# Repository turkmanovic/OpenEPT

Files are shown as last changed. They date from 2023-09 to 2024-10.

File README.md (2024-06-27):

# Energy Profiler Toolset
Easy-to-use, low-cost, open-source solution that includes compatible hardware and software sets of tools. This comprehensive solution is designed to fulfill the need for firmware energy profiling, as well as State of Charge (SoC) and State of Health (SoH) algorithm evaluation for real LiPo battery-powered embedded devices.

Official product website 
[OpenEPT](https://openept.net/)

Official [youtube](https://www.youtube.com/playlist?list=PLTG-EoxvlLos_3Sex3R0yfDCwpDYyRSOo) channel 

# Supported by
NLNet (https://nlnet.nl/)

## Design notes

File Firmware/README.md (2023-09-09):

# Firmware for energy profiler development board
Source code for STM based MCU located on EP development board

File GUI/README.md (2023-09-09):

# GUI for energy profiler development board
Source code for Qt based GUI application for energy monitoring end debugging



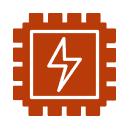
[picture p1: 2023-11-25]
GUI/OpenEPT/images/main.png

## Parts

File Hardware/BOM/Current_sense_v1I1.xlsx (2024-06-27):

Line # | Name | Description | Designator | Quantity | TargetPrice | Manufacturer 1 | Manufacturer Part Number 1 | Manufacturer Lifecycle 1 | Supplier 1 | Supplier Part Number 1 | Supplier Unit Price 1 | Supplier Subtotal 1 | ComponentLink1URL
 | 1uF | Multilayer Ceramic Capacitor, 1 uF, 50 V, ± 10%, X7R, 1206 [3216 Metric] | C1, C8, C9 | 3 | 0 | KEMET | C1206C105K5RACTU | Volume Production | Mouser | 80-C1206C105K5R | 0.26 | 0.78 | https://datasheet.ciiva.com/6074/kem-c1002-x7r-smd-6074697.pdf?src-supplier=Farnell
 | 3.3nF | Cap Ceramic 0.0033uF 100V C0G 1% SMD 1206 125°C Embossed T/R | C2 | 1 | 0 | Kyocera AVX | 12061A332FAT2A | Volume Production | Mouser | 581-12061A332FAT2A | 0.86 | 0.86 | https://datasheet.ciiva.com/11536/ccog-11536655.pdf?src-supplier=Avnet
 | 100uF/25V | Cap, 100Uf, 25V, Alu Elec, Hybrid, Smd Rohs Compliant: Yes |Wurth Elektronik 875585344001 | C3 | 1 | 0 | Wurth Electronics | 875585344001 | Unknown | Mouser | 710-875585344001 | 1.39 | 1.39
 | 0.47uF | Cap Ceramic 0.47uF 25V X7R 5% SMD 1206 125°C Embossed T/R | C4 | 1 | 0 | Kyocera AVX | 12063C474JAT2A | Volume Production | Mouser | 581-12063C474J | 0.43 | 0.43 | https://datasheet.ciiva.com/211/cx7r-211340.pdf?src-supplier=Digi-Key
 | 100n | 1206 Standard 100nF Ceramic Multilayer Cap; 50VDC; +150C; X8R Dielectric; +/-10% SMD | C5, C6, C7, C20, C21, C22, C23, C24, C25 | 9 | 0 | Kyocera AVX | 12065F104K4T2A | Volume Production | Mouser | 581-12065F104K4 | 0.172 | 1.72 | https://datasheet.ciiva.com/11787/0900766b80def347-11787814.pdf?src-supplier=Rs
 | 22uF/16V | Aluminum Electrolytic Capacitors - SMD 22uF 16V | C10, C11, C13, C14 | 4 | 0 | United Chemi-Con | MVJ16VC22RME60TP | Volume Production | Mouser, [NoParam] | 661-MVJ16VC22RM, [NoParam] |  |  | http://www.mouser.com/search/ProductDetail.aspx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
 | 10uF/16V | Aluminum Electrolytic Capacitor, 10 uF, 16 V, ± 20%, 1000 hours @ 105°C, Radial Can - SMD | C12, C15 | 2 | 0 | Panasonic | EEE-HA1C100R | Volume Production | Mouser | 667-EEE-HA1C100R | 0.23 | 0.46 | https://datasheet.ciiva.com/11777/0900766b8102e3f9-11777432.pdf?src-supplier=Rs
 | 2.2n | 1206 2.2 nF 50V ±10 % Tolerance X7R Surface Mount Multilayer Ceramic Capacitor | C16, C17, C18, C19 | 4 | 0.29 | Kyocera AVX | 12065C222KAZ2A | Volume Production | Mouser | 581-12065C222KAZ2A | 0.29 | 1.16 | https://datasheet.ciiva.com/208/flexiterm-208276.pdf?src-supplier=Digi-Key
 | SS14 | SS14 Series 500 mV 1 A 40 V Max Reverse Voltage Schottky Rectifier - DO-214AC | D1, D3, D6, D7, D10, D11 | 6 | 0 | Vishay Semiconductors | SS14-E3/61T | Volume Production | Farnell | 9551280 | 0.311 | 1.87 | https://datasheet.ciiva.com/910/ss12-910696.pdf?src-supplier=Digi-Key
 | Red | LED Red 20 mcd (Typ.) @ 25 C (Axial) 2.1 V (Typ.) @ 25 C (Forward) PCB | D2, D4, D8 | 3 | 0 | Vishay | TLMS1100-GS08 | Volume Production | Farnell | 1440338 | 0.323 | 0.969 | https://datasheet.ciiva.com/4689/sml-lxl1206gc-tr-115211-4689614.pdf?src-supplier=Mouser
 | Green | Led, Quasarbrite, Green, T-3/4 (1.8Mm), 574 Nm, 2.2 V, 20 Ma, 170 Mcd Rohs Compliant: Yes | D5 | 1 | 0 | Vishay Lite-On | LTST-C190GKT | Volume Production | Mouser | 859-LTST-C190GKT | 0.23 | 0.23 | https://datasheet.ciiva.com/30105/sml-lxl1209sugc-tr-30105147.pdf?src-supplier=Onlinecomponents.com
 | 3V3 Zener | MMELF, 500mW, 2%, Small Signal Zener Diode | D9 | 1 | 0 | ON Semiconductor | MM5Z3V3T1G | Volume Production | Mouser | 863-MM5Z3V3T1G | 0.18 | 0.18
 | 2_PIN_254 | Conn Unshrouded Header PL 2 POS 2.54mm Solder ST Thru-Hole | J1, J5, J7, J10, J22 | 5 | 0 | Omron | XG8T-0241 | Volume Production | Mouser | 653-XG8T0241 | 0.16 | 0.8 | https://datasheet.ciiva.com/48561/en-xg8t-48561514.pdf?src-supplier=Avnet
 | Red Connector | Connector, Pcb, 2CONTACTS | J2, J4, J6 | 3 | 0 | Deltron | 571-0500-01 | Volume Production | Farnell | 1101127 | 1.39 | 4.17 | http://www.farnell.com/datasheets/2007771.pdf?src-supplier=Farnell
 | Black Connector | Connector, Pcb, 2CONTACTS | J3 | 1 | 0 | Deltron | 571-0100 | Volume Production | Farnell | 1494595 | 1.17 | 1.17 | https://datasheet.ciiva.com/12074/deltron-571-0100-4mm-90deg-single-socket-data-372703-12074316.pdf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
 | Battery connector clamp | Conn PC Board Terminal Block Receptacle 2 POS 2.54mm RA Through Hole 10A | J8 | 1 | 0 | TE Connectivity | 282834-2 | Volume Production | Farnell | 2112482 | 1.19 | 1.19 | https://datasheet.ciiva.com/16386/282834-2-16386363.pdf?src-supplier=Future+Electronics
 | PH2.0 battery connector | Connector, Header, 2Pos, 1Rows, 2Mm Rohs Compliant: Yes | J9 | 1 | 0 | TE Connectivity | 292133-2 | Volume Production | Mouser | 571-292133-2 | 0.4 | 0.4 | https://datasheet.ciiva.com/734/eng-cd-292133-p-734147.pdf?src-supplier=Digikey
 | Push Button | Switch Tactile N.O. SPST Round Button Gull Wing 0.05A 12VDC 1.57N SMD Tube | J11 | 1 | 0 | Diptronics | DTSM-61N-V-B | Volume Production | Mouser | 113-DTSM-61N-V-B |  |  | https://datasheet.ciiva.com/26337/707546-da-01-en-smd-taster-26337236.pdf?src-supplier=Conrad
 | 6 pin 2.54 mm male | 2.54mm (0.1") Pitch SIL Vertical PC Tail Pin Header, 7mm mating pin height, tin, 6 contacts | J12 | 1 | 0 | Harwin | M20-9730646 | Volume Production | Digikey | 952-1985-ND | 0.33 | 0.33 | https://datasheet.ciiva.com/6830/m20-973-6830695.pdf?src-supplier=Digi-Key
 | 10 pin male 2.54mm pitch | Conn Unshrouded Header HDR 50 POS 2.54mm Solder ST Thru-Hole Box | J13 | 1 | 0 | TE Connectivity | 5-825433-0 | Volume Production | Farnell | 3417736 | 3.94 | 3.94 | https://datasheet.ciiva.com/11751/0900766b800304ef-11751249.pdf?src-supplier=Rs
 | 20 pin 2.54 male straight | Conn, Header, 20POS, 2ROW, 2.54MM Rohs Compliant: Yes | J14 | 1 | 0 | Harwin | M20-9721045 | Volume Production | Mouser | 855-M20-9721045 | 0.98 | 0.98 | http://www.mouser.com/ds/2/181/Harwin_Product_Catalog_page_207-1131241.pdf?src-supplier=Mouser
 | 8 pin 2.54 male header | 2.54MM Pitch, Srsw, T/h, H | J15 | 1 | 0 | Molex | 0878910808 | Unknown | Mouser | 538-87891-0808 | 2.55 | 2.55
 | 28 pin male right angle | Headers & Wire Housings 28P 2R BRKAWAY HDR 2.54MM RA L-PRO SN | J16 | 1 | 0 | Molex | 0717640028 | Obsolete | Mouser | 538-71764-0028 | 5.14 | 5.14 | https://datasheet.ciiva.com/6862/717640004-sd-6862000.pdf?src-supplier=Digikey
 | power 8 pin | 2.54MM Pitch, Srsw, T/h, H | J17 | 1 | 0 | Molex | 0878910808 | Unknown | Mouser | 538-87891-0808 | 2.55 | 2.55
 | 4907 | USB C SMT / THM Jack Connector - Power Only - Pack of 10 | J18 | 1 | 0 | Keystone Electronics | 4907 | Volume Production | Mouser | 534-4907 | 0.2 | 0.2 | https://datasheet.ciiva.com/16507/m60-2p52-16507735.pdf?src-supplier=Future+Electronics
 | PCB-MB-01 | Installation BLock Colour: Transparent Material: Nylon 6/6 RMS-01 | J19, J20, J24, J25 | 4 | 0 | Essentra | PCB-MB-01 | Volume Production | Mouser | 144-PCB-MB-01 | 0.36 | 1.44 | https://datasheet.ciiva.com/11835/0900766b8002e29e-11835600.pdf?src-supplier=Rs
 | 39-10-1020 | Connector Wire to Board Header 2 Position 4.2mm Solder Right Angle Thru-Hole Bag | J21 | 1 | 0 | Molex | 039301020 | Volume Production | Mouser | 538-39-30-1020 | 0.56 | 0.56 | https://www.molex.com/pdm_docs/sd/039301020_sd.pdf?src-supplier=Digikey
 | Heat Sink | Heat Sink Passive TO-220 Radial Thru-Hole Aluminum 5.5°C/W Black Anodized | J23 | 1 | 0 | Aavid Thermalloy | 529702B02500G | Volume Production | Mouser | 532-529702B25G | 1.99 | 1.99 | https://datasheet.ciiva.com/15182/getdatasheetpartid-42755-15182474.pdf?src-supplier=Verical
 | 1uH | Drum Core Shielded Power Inductor Wirewound Ferrite 1uH 20% 1MHz 9.5A SMD T/R | L1, L2 | 2 | 0 | Pulse | PA4333.102NLT | Volume Production | Digikey | 553-3294-1-ND | 0.85 | 1.7 | http://productfinder.pulseeng.com/products/datasheets/P762.pdf?src-supplier=Digikey
 | TSM500P02CX RFG | Transistor Mosfet P-ch 20V 4.7A 3-PIN SOT-23 T/r | M1, M7, M13 | 3 | 0 | Taiwan Semiconductor | TSM500P02CX RFG | Volume Production | Digikey | TSM500P02CXRFGCT-ND | 0.5 | 1.5 | http://www.taiwansemi.com/products/datasheet/TSM500P02CX_A14.pdf?src-supplier=Digi-Key
 | 2N7002L | Mosfet, N-ch, Vdss 60VDC, Rds(on) 7.5 Ohms, ID+/-115MA, SOT-23 (TO-236), Pd 225MW, -55C | M2, M3, M4, M6, M8, M9, M12, M14, M15, M16, M18, M19, M20, M21, M22, M23, M24 | 17 | 0 | ON Semiconductor | 2N7002LT3G | Volume Production | Farnell | 1764537 | 0.125 | 2.13 | http://www.farnell.com/datasheets/2354034.pdf?src-supplier=Farnell
 | IRF4905STRLPBF | Transistor: P-MOSFET; unipolar; -55V; -74A; 0.02ohm; 3.8W; -55+175 deg.C; SMD; TO263 (D2PAK) | M5, M10, M11 | 3 | 0 | Infineon | IRF4905STRLPBF | Not Recommended for New Design | Farnell | 1298511 | 2.49 | 7.47
 | TK4R3E06PL,S1X | X35 Pb-F Power Mosfet Transistor To-220 Pd=87W F=1Mhz | M17 | 1 | 0 | Toshiba | TK4R3E06PL,S1X | Unknown | Mouser | 757-TK4R3E06PLS1X | 1.44 | 1.44
 | TSM250N02CX RFG | Transistor Power MOSFET N-CH 20V 5.8A 3-Pin SOT-23 T/R | M25, M26 | 2 | 0 | Taiwan Semiconductor | TSM250N02CX RFG | Volume Production | Mouser | 821-TSM250N02CXRFG | 0.43 | 0.86 | http://www.taiwansemi.com/products/datasheet/TSM250N02CX_A14.pdf?src-supplier=Digikey
 | 220 | Res, Aec-Q200, 220R, 1%, 0.5W, 1206 Rohs Compliant: Yes |Vishay RCC1206220RFKEA | R1, R19, R22, R24, R25, R31, R40 | 7 | 0 | Vishay Dale | RCC1206220RFKEA | Unknown | Mouser | 71-RCC1206220RFKEA | 0.128 | 1.28 | https://datasheet.octopart.com/RCC1206220RFKEA-Vishay-datasheet-151891907.pdf?src-supplier=Element14
 | 10k | SMD Chip Resistor, 10 kOhm, ± 5%, 250 mW, 1206 [3216 Metric], Thick Film, General Purpose | R2, R11, R14, R26, R39, R44, R45, R50, R51, R53, R54, R55, R57, R58, R60, R62, R63, R68, R69, R70 | 20 | 0 | Bourns | CR1206-JW-103ELF | Volume Production | Farnell | 2333546 | 0.0164 | 0.328 | https://datasheet.ciiva.com/6547/chpreztr-6547381.pdf?src-supplier=Digi-Key
 | 56k | Res Thick Film 1206 56K Ohm 1% 1/4W ±100ppm/°C Molded SMD SMD Paper Tape on Plastic Reel | R3 | 1 | 0 | Bourns | CR1206-FX-5602ELF | Volume Production | Mouser | 652-CR1206FX-5602ELF | 0.1 | 0.1 | https://datasheet.ciiva.com/9121/chpreztr-9121174.pdf?src-supplier=Avnet
 | 100k | Res Thick Film 1206 100kOhm 1/4W Molded Paper T/R | R4, R6, R7, R9, R18, R23, R27, R30, R32, R35, R36, R38, R46, R47, R49 | 15 | 0 | Vishay Dale | RCG1206100KJNEA | Volume Production | Mouser | 71-RCG1206100KJNEA | 0.139 | 2.09 | http://www.mouser.com/ds/2/427/rcge3-254226.pdf?src-supplier=Mouser
 | 680k | RES SMD 680K OHM 5% 1/4W 1206 | R5 | 1 | 0 | Bourns | CR1206-JW-684ELF | Volume Production | Digikey | 118-CR1206-JW-684ELFCT-ND | 0.1 | 0.1 | https://datasheet.ciiva.com/5544/chpreztr-5544750.pdf?src-supplier=Mouser
 | 560 | Res Thkflm D25/1206 560R Ohm 1% 100 ET6 E3 SMD | R8, R10, R34 | 3 | 0 | Vishay Dale | CRCW1206560RFKEC | Not Recommended for New Design | Mouser | 71-CRCW1206560RFKEC | 0.1 | 0.3 | http://www.vishay.com/docs/20035/dcrcwe3.pdf?src-supplier=Digi-Key
 | 220k | Resistor Thick Film 220kOhm 5% 2-Pin 1206 T/R | R12, R13 | 2 | 0 | Bourns | CHP1206AJW-224ELF | Unknown | Farnell | 3464682 | 0.538 | 1.08
 | 33k | SMD Chip Resistor, 33 kOhm, ± 5%, 250 mW, 1206 [3216 Metric], Thick Film, General Purpose | R15, R17, R41 | 3 | 0 | Yageo | RC1206JR-0733KL | Volume Production | Farnell | 9240705 | 0.0207 | 0.207 | https://datasheet.ciiva.com/29181/402729-da-01-en-smd-widerstand-chip1206-33-kohm-29181369.pdf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
 | 1M | SMD Chip Resistor, 1 MOhm, ± 5%, 250 mW, 1206 [3216 Metric], Thick Film, General Purpose | R16 | 1 | 0 | Bourns | CR1206-JW-105ELF | Volume Production | Farnell | 2469514 | 0.009 | 0.09 | https://datasheet.ciiva.com/9123/chpreztr-9123660.pdf?src-supplier=Avnet
 | 1k | Res Thick Film 1206 1kOhm 5% 1/4W ±200ppm/K Molded Paper Tape | R20, R21, R37, R43, R48 | 5 | 0 | Vishay Dale | RCA12061K00JNEA | Volume Production | Mouser | 71-RCA12061K00JNEA | 0.059 | 0.59 | http://www.vishay.com/docs/20037/rcae3.pdf?src-supplier=Digi-Key
 | 45mOhm | CURRENT SENSE, RESISTOR, WSLP1206.0451%EAe3 | Vishay Dale WSLP1206R0450FEA | R28 | 1 | 0 | Vishay | WSLP1206R0450FEA | Unknown | Digikey | WSLP1206R0450FEA-ND
 | 6.8k | Res Thick Film 1206 6.8K Ohm 1% 1/4W ±100ppm/°C Molded SMD SMD Paper Tape on Plastic Reel | R29 | 1 | 0 | Bourns | CR1206-FX-6801ELF | Volume Production | Mouser | 652-CR1206FX-6801ELF | 0.1 | 0.1 | https://datasheet.ciiva.com/9122/chpreztr-9122586.pdf?src-supplier=Avnet
 | 100 | SMD Chip Resistor, 100 Ohm, ± 5%, 250 mW, 1206 [3216 Metric], Thick Film, General Purpose | R33, R42, R64, R65, R66, R67 | 6 | 0 | Bourns | CR1206-JW-101ELF | Volume Production | Mouser | 652-CR1206JW-101ELF | 0.015 | 0.15 | https://datasheet.ciiva.com/9120/chpreztr-9120757.pdf?src-supplier=Avnet
 | 75mOhm | Res Current Sense Metal Strip 2512 0.075 Ohm 1% 3W ±25ppm/°C Molded Emboss T/R | R52 | 1 | 0 | CGS | TLRP3A30CR075FTE | Volume Production | Farnell | 3782978 | 0.476 | 0.476
 | 10 | Resistor, ResHighPowerA 1206 10R 1% 3/4W TC100 | R56, R59 | 2 | 0 | Bourns | CMP1206AFX-10R0ELF | Unknown | Mouser | 652-CMP1206AFX-10R0L | 0.39 | 0.78
 | 3.3k | Res Thick Film 1206 3.3K Ohm 1% 1/4W ±100ppm/°C Molded SMD SMD Paper Tape on Plastic Reel | R61 | 1 | 0 | Bourns | CR1206-FX-3301ELF | Volume Production | Digikey | CR1206-FX-3301ELFCT-ND | 0.1 | 0.1 | https://datasheet.ciiva.com/41449/001055537-da-01-en-smd-wid-cr1206-fx-3301elf-3-3k-ohm-1-4w-41449983.pdf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
 | 3V3 Regulator | IC REG LDO 3.3V 1A SOT223 | U1 | 1 | 0 | TI National Semiconductor | LM3940IMP-3.3/NOPB | Volume Production | Mouser | 926-LM3940IMP3.3NOPB | 1.9 | 1.9
 | TPS60400 | 60mA Charge Pump Voltage Inverter with Variable Switching Frequency 5-SOT-23 -40 to 85 | U2 | 1 | 0 | Texas Instruments | TPS60400DBVT | Volume Production | Farnell | 3123047 | 1.21 | 1.21 | https://datasheet.ciiva.com/15114/getdatasheetpartid-256453-15114097.pdf?src-supplier=Verical
 | TPS61023DRLR | 3.7-A boost converter with 0.5-V ultra-low input voltage 6-SOT-5X3 -40 to 125 | U3, U4 | 2 | 0 | Texas Instruments | TPS61023DRLR | Volume Production | Mouser | 595-TPS61023DRLR | 0.98 | 1.96 | http://www.ti.com/general/docs/suppproductinfo.tsp?distId=10&src-supplier=Digikey
 | RGB diode | WL-SFTW SMT full-color TOP LED waterclear | U5 | 1 | 0 | Wurth Electronics | 150352M173300 | Unknown | Farnell | 2900778 | 0.635 | 0.635 | http://www.farnell.com/datasheets/2621660.pdf?src-supplier=Farnell
 | INA296A1SOIC8 | Operational Amplifier, 1 Func, 150uV Offset-Max, PDSO5 | U6 | 1 | 0 | Texas Instruments | INA296A1IDDFR | Volume Production | Digikey | 296-INA296A1IDDFRCT-ND | 3.61 | 3.61
 | LM358DR | Operational Amplifier, Dual, 700 Khz, 2, 0.3 V/ S, 3V To 32V, 1.5V To 16V, Soic, 8 Rohs Compliant: Yes | U7, U8, U9 | 3 | 0 | Texas Instruments | LM358DR | Volume Production | Digikey | 296-LM358DRCT-ND | 0.41 | 1.23 | https://datasheet.ciiva.com/1795/lm358-1795488.pdf?src-supplier=Digi-Key
 | M24C32-WMN6P | M24C32 Series 32 Kb (4 K x 8) 2.5 V SMT Serial I²C Bus EEPROM - SOIC-8 | U10 | 1 | 0 | STMicroelectronics | M24C32-WMN6P | Not Recommended for New Design | Mouser | 511-M24C32-WMN6P | 0.23 | 0.23 | https://datasheet.ciiva.com/34303/1996428-34303716.pdf?src-supplier=Jameco

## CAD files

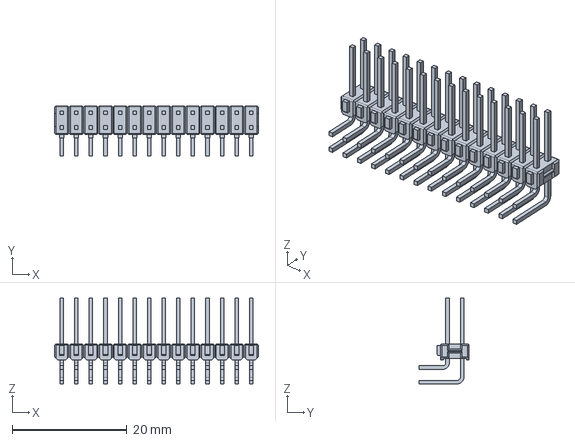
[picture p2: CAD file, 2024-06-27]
Hardware/Source Files KiCad/ALTIUM_EMBEDDED_MODELS/1-826664-4--3DModel-STEP-1.STEP
35.6 x 8.77 x 15.0 mm

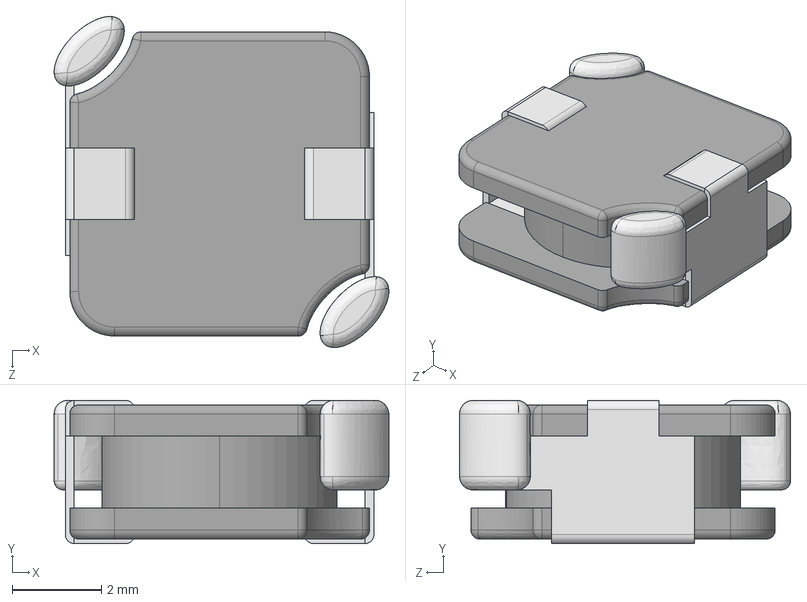
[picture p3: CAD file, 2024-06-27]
Hardware/Source Files KiCad/ALTIUM_EMBEDDED_MODELS/User Library-PA4333_7_4x6_8x3_2mm.step
7.48 x 3.20 x 7.40 mm

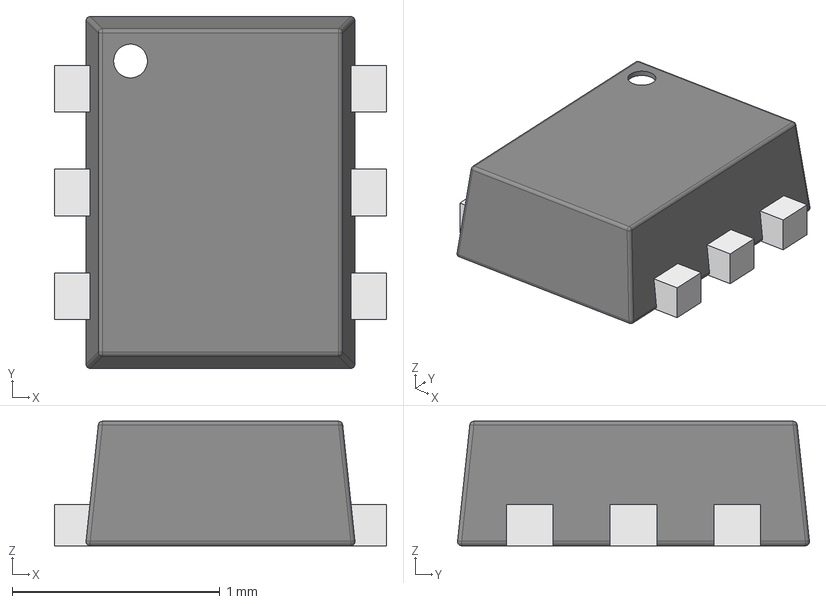
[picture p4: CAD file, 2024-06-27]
Hardware/Source Files KiCad/ALTIUM_EMBEDDED_MODELS/SOT563.step
1.60 x 1.70 x 0.6 mm
lead x 6

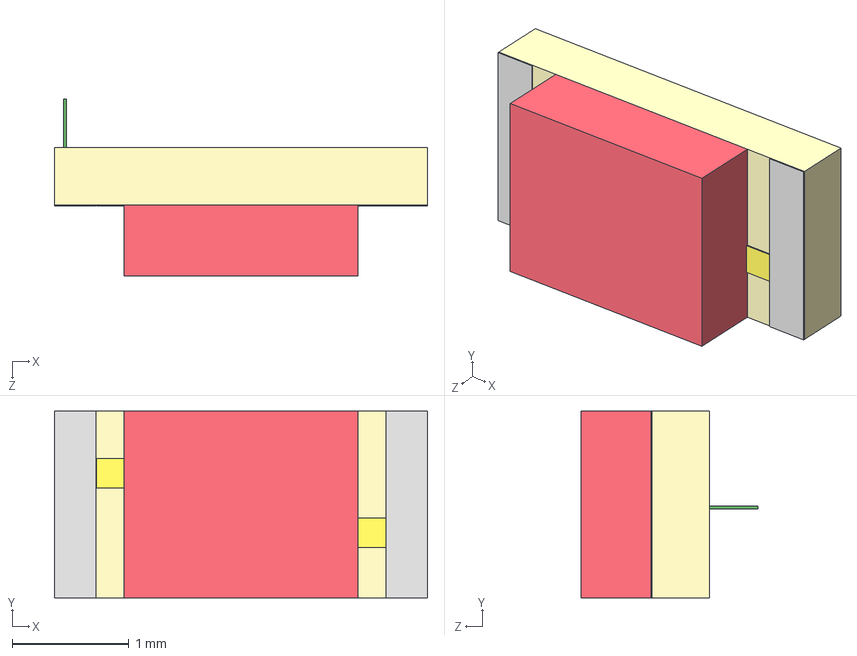
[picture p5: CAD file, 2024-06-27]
Hardware/Source Files KiCad/ALTIUM_EMBEDDED_MODELS/User Library-LED1206R.STEP
3.20 x 1.60 x 1.52 mm
Extruded2
Extruded1
Extruded x 2
Extruded4
Extruded3
Board

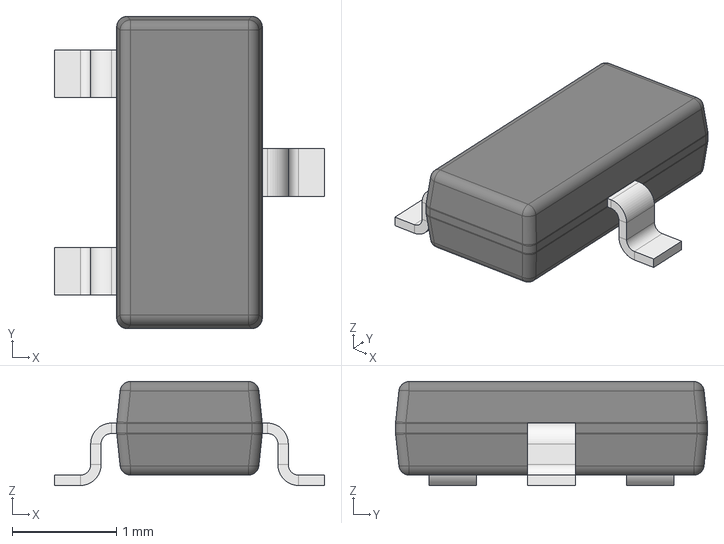
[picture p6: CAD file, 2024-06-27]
Hardware/Source Files KiCad/ALTIUM_EMBEDDED_MODELS/SOT95P240X100-3N.step
2.60 x 3.00 x 1.00 mm
Leader x 3

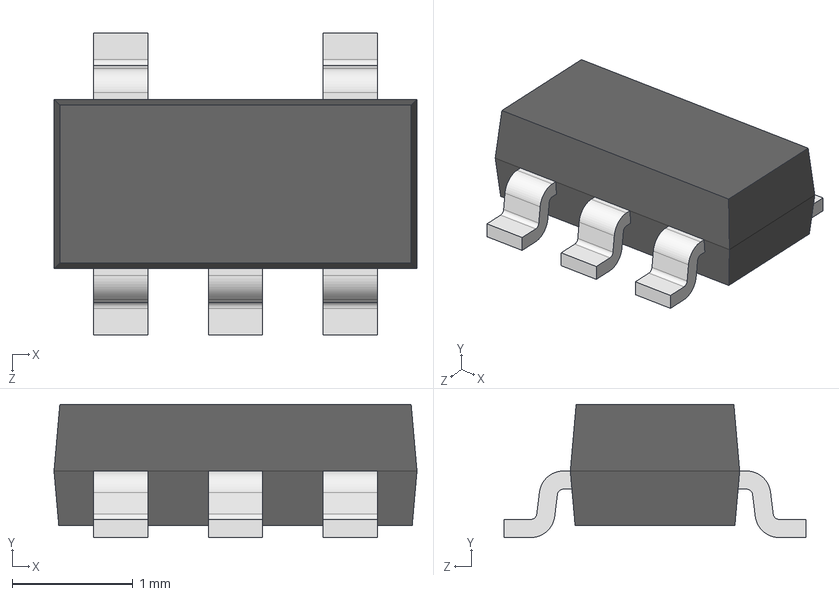
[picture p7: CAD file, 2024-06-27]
Hardware/Source Files KiCad/ALTIUM_EMBEDDED_MODELS/CircuitWorks-SOT-23-5.step
3.00 x 1.10 x 2.50 mm

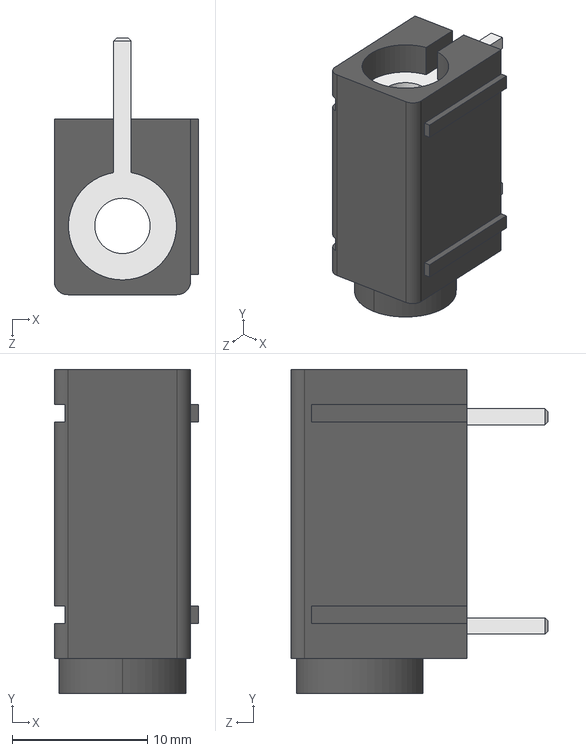
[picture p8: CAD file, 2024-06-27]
Hardware/Source Files KiCad/ALTIUM_EMBEDDED_MODELS/User Library-Multicomp_24_243_2.step
10.7 x 24.0 x 19.0 mm

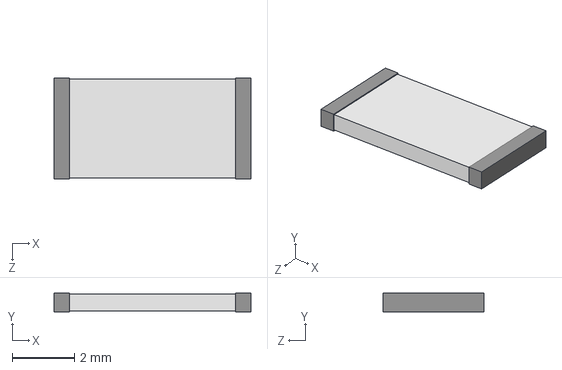
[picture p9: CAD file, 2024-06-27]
Hardware/Source Files KiCad/ALTIUM_EMBEDDED_MODELS/CircuitWorks-RESISTOR 2512.step
6.35 x 0.61 x 3.26 mm

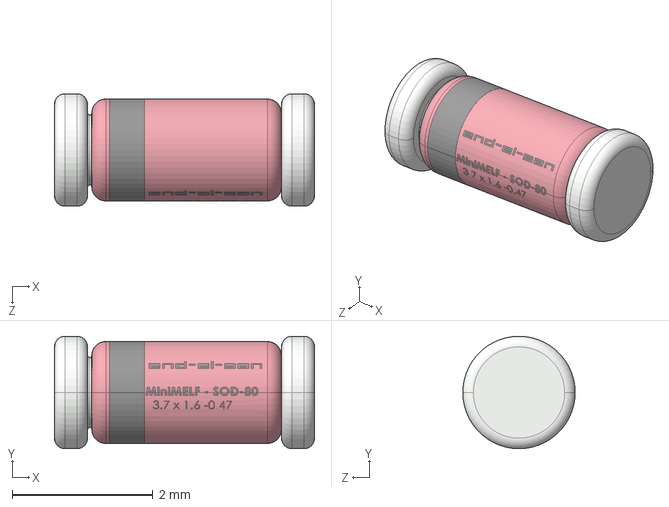
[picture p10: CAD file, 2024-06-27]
Hardware/Source Files KiCad/ALTIUM_EMBEDDED_MODELS/User Library-MiniMelf-2.step
3.70 x 1.60 x 1.60 mm

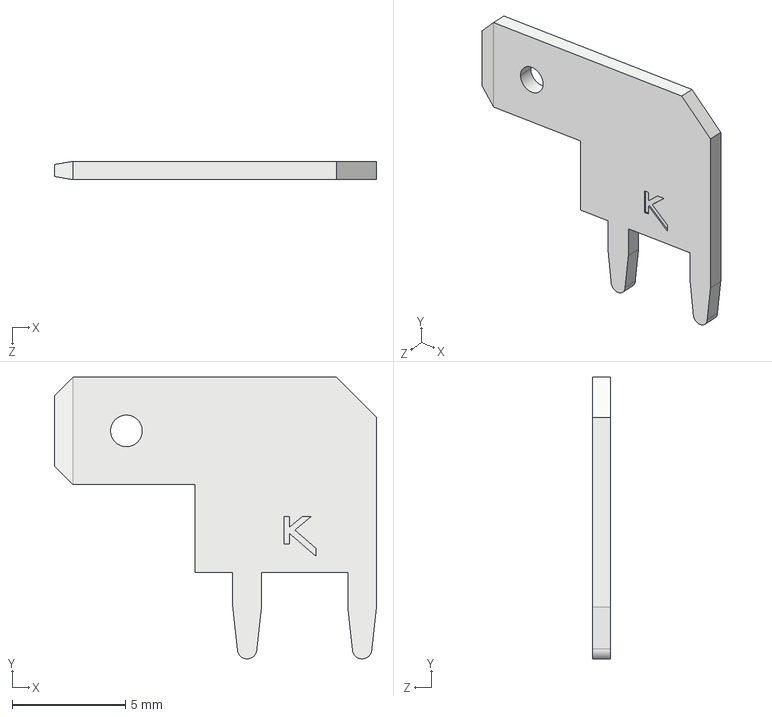
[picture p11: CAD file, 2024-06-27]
Hardware/Source Files KiCad/ALTIUM_EMBEDDED_MODELS/4907--3DModel-STEP-630548.STEP
14.2 x 12.4 x 0.813 mm

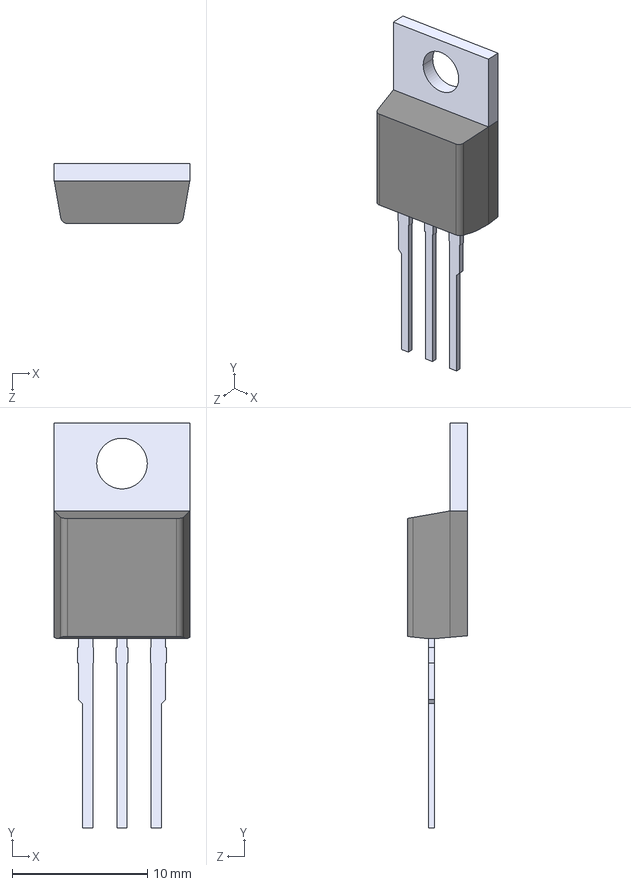
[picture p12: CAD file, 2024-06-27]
Hardware/Source Files KiCad/ALTIUM_EMBEDDED_MODELS/step_temp.STEP
10.0 x 29.9 x 4.44 mm

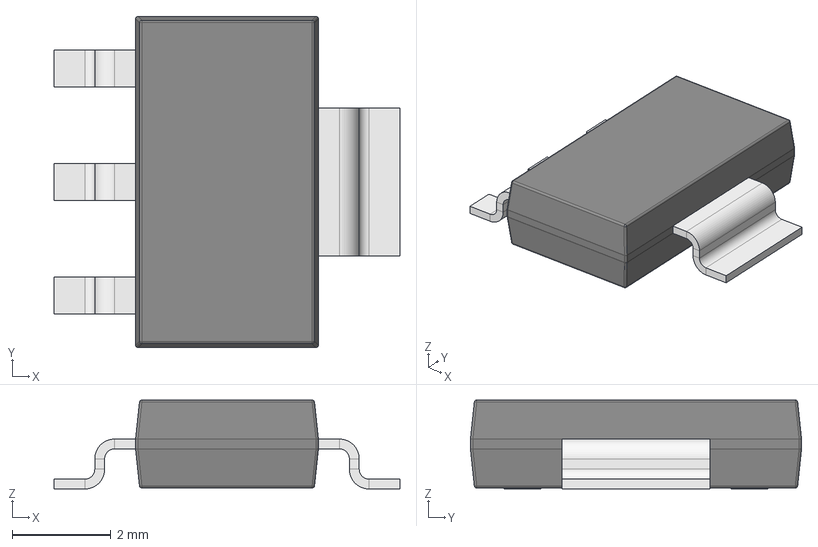
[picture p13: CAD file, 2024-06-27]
Hardware/Source Files KiCad/ALTIUM_EMBEDDED_MODELS/SOT230P700X180-4N.step
7.00 x 6.70 x 1.80 mm
Lead x 3
Tab

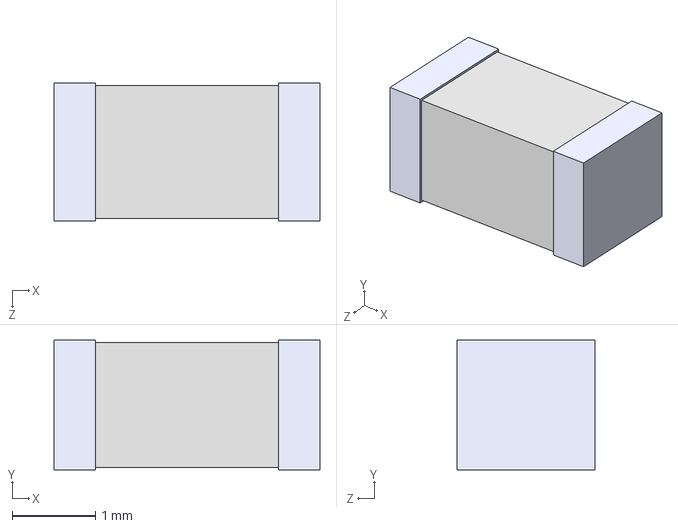
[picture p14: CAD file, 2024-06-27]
Hardware/Source Files KiCad/ALTIUM_EMBEDDED_MODELS/CircuitWorks-CAPACITOR 1206.step
3.20 x 1.56 x 1.66 mm

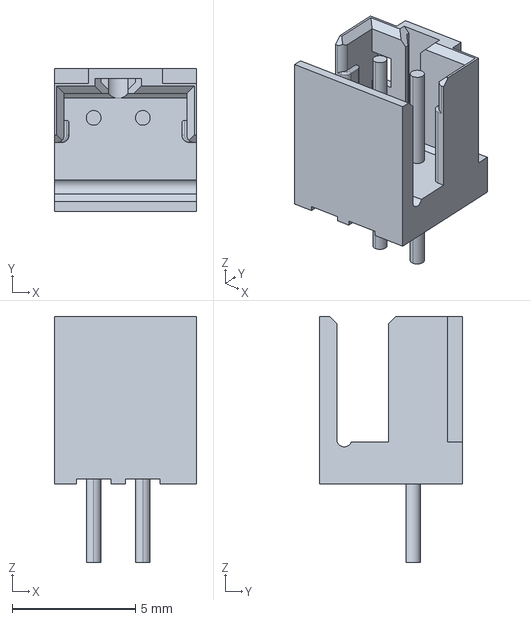
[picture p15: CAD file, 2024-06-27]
Hardware/Source Files KiCad/ALTIUM_EMBEDDED_MODELS/c-292133-2-a-3d.stp
5.79 x 5.80 x 10.0 mm

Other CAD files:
Hardware/Source Files KiCad/ALTIUM_EMBEDDED_MODELS/User Library-LED1206G.STEP
Hardware/Source Files KiCad/ALTIUM_EMBEDDED_MODELS/User Library-Multicomp_24_243_1.step
Hardware/Source Files KiCad/ALTIUM_EMBEDDED_MODELS/DPAK254P1524X483-3L.step
Hardware/Source Files KiCad/ALTIUM_EMBEDDED_MODELS/c-282834-2-c-3d.stp
Hardware/Source Files KiCad/ALTIUM_EMBEDDED_MODELS/039301020.stp
Hardware/Source Files KiCad/ALTIUM_EMBEDDED_MODELS/150352M173300--3DModel-STEP-269445.STEP
Hardware/Source Files KiCad/ALTIUM_EMBEDDED_MODELS/529702B02500G--3DModel-STEP-510211.STEP
Hardware/Source Files KiCad/ALTIUM_EMBEDDED_MODELS/66100211622.stp
Hardware/Source Files KiCad/ALTIUM_EMBEDDED_MODELS/DIOM5026X23N.step
Hardware/Source Files KiCad/ALTIUM_EMBEDDED_MODELS/SOIC127P600X175-8N.step
Hardware/Source Files KiCad/ALTIUM_EMBEDDED_MODELS/SSQ-110-02-T-D-RA.stp
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

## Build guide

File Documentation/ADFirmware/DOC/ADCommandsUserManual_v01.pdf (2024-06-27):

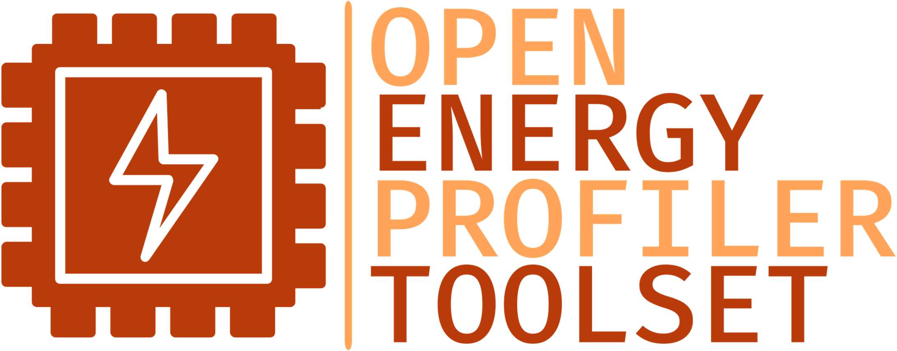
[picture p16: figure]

Acquisition Device’s Commands Description

Version 0.1

Revision history
Authors | Date | Version | Description
Dimitrije Lilić, Haris Turkmanović | 03.03.2024 | 0.1 | Initial commands description

## Contents

### 1. Control service description

Within the device firmware, the logic for control and status messages is encapsulated within a distinct service. This service is responsible for receiving control messages, parsing their content, executing the appropriate actions based on the message content, and generating responses accordingly. The core logic and operational mechanisms of this service are depicted in the Figure 1.

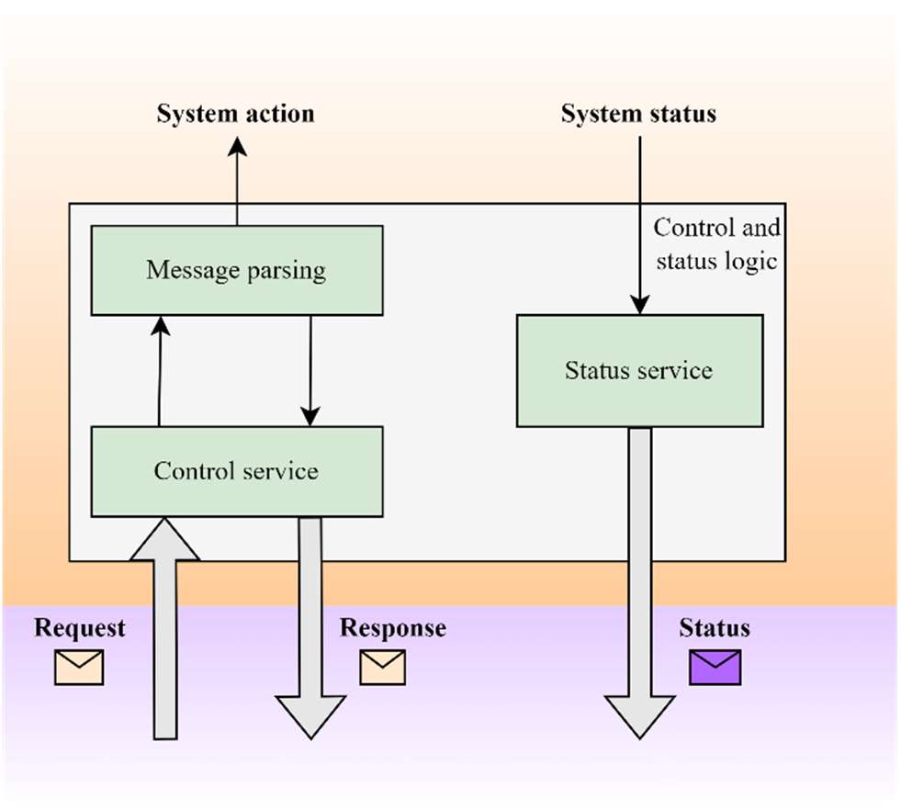
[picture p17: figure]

Control messages are transmitted to the Acquisition device in the form of control message requests. These requests originate from the HOST side and are transmitted through a previously established TCP port on the Acquisition device. Upon receipt, the control message request is processed within the Control service server task and forwarded to the Message Parsing logic for analysis of the message content. The Message Parsing logic, which is an integral part of the Control service, is responsible for examining the content of received control messages and invoking the appropriate callback function assigned to each specific control message. Upon execution of the callback functions corresponding to the requested control messages, responses are generated based on the results of the function execution. These responses are then transmitted back to the HOST machine.
All control messages are in ASCII format with predefined structures. Control messages structures are following:
Control message type: | Request
Control message structure: | device<ws>[<wsa><argumentsList>]<eom>
Fields description
Field name | Field description | Optional/Mandatory
<ws> | White space character | Mandatory
<argumentsList> | List of command arguments defined in -
| key=value format separated by <ws>. | Optional
<wsa> | White space character inside arguments
| list block | Optional
<eom> | End of message is compound of two
| ASCI characters: ‘\r\n’ | Mandatory

Figure 1 - Control and status service logic

Control message type | Response
Control message structure | <mps><ws><ces>[<wsa><argument List>]<eom>
Fields description
Field name | Field description | Optional/Mandatory
<mps> | Message parsing status. There are two possible values:

### 1. OK – message is successfully

| parsed.

### 2. ERROR - there are issues during

| parsing messages. Usually caused by invalid messages format or unsupported command.

Mandatory

<ws> | White space character | Mandatory
<ces> | Callback execution status. There are two possible values:

### 1. OK – callback is successfully

| executed.

### 2. ERROR – there is an error during

| callback execution.
| Usually caused by invalid messages format or unsupported command.

Mandatory

<wsa> | White space character inside arguments list block

Optional

<argumentsList> | List of command arguments defined in - key=value format separated by <wsa>.

Optional

<eom> | End of message is compound of two ASCI characters: ‘\r\n’

Mandatory

### 2. Supported commands list

Here will be listed all supported commands.

### 2.1. General device commands

### 2.1.1. Ping device

This command is used to ping device and obtain device name

### 2.1.2. Set device name

This command is used to set device name

Command name
device hello
Command Arguments
Key | Value description

Return Value

<status><ws><deviceName><eom>

Return arguments
Key | Value description
deviceName | Acquisition Device name
Example

Command: device hello
Response: OK AcqDevice\r\n
Example description: | Ping device to obtain device name

Command name
device setname
Command Arguments
Key | Value description
-value | Specify device name
Return Value

<status><eom>

Return arguments
Key | Value description
/ | /

### 2.2. Status link related commands

Here are listed all information related to the commands that operates over status link.

### 2.2.1. Create status link

Create status link.

Example

Command: device setname -value=OpenEPT
Response: OK \r\n
Example description: | Set device name to “OpenEPT” and get OK as response to notify that device is successfully set

Command name
device slink create
Command Arguments
Key | Value description

Return Value

| <status><ws><linkInstanceNo><ws><eom>

Return arguments
Key | Value description
linkInstanceNo | Link Instance number
Example

Command: device slink create
Response: OK 0 \r\n
Example description: | Create status link, and get instance number of link created from device

### 2.2.2. Send status message over IP

Send message over status link

Command name
device slink send Proveri
Command Arguments
Key | Value description
-value | Message to send over status link
Return Value

<status><ws><””><ws><eom>

Return arguments
Key | Value description
| Example

Command: device slink send –value=?
Response: OK \r\n
Example description: | Send message over status link to device

### 2.3. Stream related commands

Here are listed all information related to the commands that operates over stream.

### 2.3.1. Create stream link

Create stream link client that will send stream samples on predefined server. Server IP information are sent to Acquisition device though this command.

Command name
device stream create
Command Arguments
Key | Value description
-value | Stream server ip in ipv4 format
Return Value

<status><ws><OK><ws><eom>

Return arguments
Key | Value description
streamIDString | Stream ID
Example

Command: device stream create –sid=0 –value=192.168.2.100
Response: OK 0 \r\n
Example description: | Creates stream link with IP address and gets grom device unique stream ID identifier.

### 2.3.2. Start samples acquisition

Start stream link that is defined with stream ID.

### 2.3.3. Stop samples acquisition

Stop stream link that is defined with stream ID.

Command name
device stream start
Command Arguments
Key | Value description
-sid | Unique stream ID obtained by device stream create command

Return Value

<status><ws><OK><ws><eom>

Return arguments
Key | Value description
OK | Return value OK
Example

Command: device stream start –sid=0
Response: OK OK \r\n
Example description: | Starts streaming of specified of stream with specified ID

Command name
device stream stop
Command Arguments
Key | Value description
-sid | Unique stream ID obtained by device stream create command

Return Value

<status><ws><OK><ws><eom>

Return arguments
Key | Value description
OK | Return value OK
Example

Command: device stream stop
Response: OK OK \r\n
Example description: | Stops streaming of specified of stream with specified ID

### 2.4. Analog input related command

Here are listed all information related to the operations of analog input.

### 2.4.1. Set Analog input resolution

Set analog input adc resolution by utilizing system service.

Command name
device adc chresolution set Command Arguments
Key | Value description
-sid | Unique stream ID obtained by device stream create command
-value | Stream’s ADC resolution{16, 14, 12, 10} [bit]
Return Value

<status><ws><OK><ws><eom>

Return arguments
Key | Value description
OK | Return value OK
Example

Command: device adc chresolution set –sid=0 –value=12
Response: OK OK \r\n
Example description: | Set ADC resolution 12 to stream with ID 0. Command returns OK to notify that everything is set successfully.

### 2.4.2. Get Analog input resolution

Get analog input adc resolution by utilizing system service.

Command name
device adc chresolution get Command Arguments
Key | Value description
-sid | Unique stream ID obtained by device stream create command

Return Value

<status><ws><resolution><ws><eom>

Return arguments
Key | Value description
Resolution | Resolution read from device
Example

Command: device adc chresolution get –sid=0
Response: OK 16bit \r\n
Example description: | Get ADC resolution of stream with ID 0. Command returns resolution to notify that everything is set successfully.

### 2.4.3. Set Analog input clock divider

Set analog input adc clock divider by utilizing system service.

Command name
device adc chclkdiv set
Command Arguments
Key | Value description
-sid | Unique stream ID obtained by device stream create command
-value | Stream’s ADC clock divider {1, 4, 8, 16, 32, 64, 128, 256}

Return Value

<status><ws><OK><ws><eom>

Return arguments
Key | Value description
OK | Return value OK
Example

Command: device adc chclkdiv set –sid=0 –value=16
Response: OK OK \r\n
Example description: | Set ADC clock div 16 to stream with ID 0. Command returns OK to notify that everything is set successfully.

### 2.4.4. Get Analog input clock divider

Set analog input adc clock divider by utilizing system service.

Command name
device adc chclkdiv get
Command Arguments
Key | Value description
-sid | Unique stream ID obtained by device stream create command

Return Value

<status><ws><clockDivider><ws><eom>

Return arguments
Key | Value description
clockDivider | Clock divider read from device
Example

Command: device adc chclkdiv get –sid=0
Response: OK 16 \r\n
Example description: | Get ADC clock div of stream with ID 0. Command returns clock div to notify that everything is set successfully.

### 2.4.5. Set Analog input channel sampling time

Set analog input adc sampling time by utilizing system service.

Command name
device adc chstime set
Command Arguments
Key | Value description
-sid | Unique stream ID obtained by device stream create command
-value | Stream’s ADC channel sampling time {1, 2, 8, 16, 32, 64, 378, 810}

Return Value

<status><ws><OK><ws><eom>

Return arguments
Key | Value description
OK | Return value OK
Example

Command: device adc chstime set –sid=0 –value=64
Response: OK OK \r\n
Example description: | Set ADC channel sampling time 64 to stream with ID 0. Command returns OK to notify that everything is set successfully.

### 2.4.6. Get Analog input sampling time

Get analog input adc sampling time by utilizing system service.

Command name
device adc chstime get
Command Arguments
Key | Value description
-sid | Unique stream ID obtained by device stream create command

Return Value

<status><ws><samplingTime><ws><eom>

Return arguments
Key | Value description
samplingTime | Sampling time read from device
Example

Command: device adc chstime get –sid=0
Response: OK 32 \r\n
Example description: | Get ADC channel sampling time of stream with ID 0. Command returns channel sampling time to notify that everything is set successfully.

### 2.4.7. Set Analog input averaging ratio

Set analog input adc averaging ratio by utilizing system service.

Command name
device adc chavrratio set
Command Arguments
Key | Value description
-sid | Unique stream ID obtained by device stream create command
-value | Stream’s ADC averaging ratio {1, 2, 4, 8, 16, 32, 64, 128, 256}

Return Value

<status><ws><OK><ws><eom>

Return arguments
Key | Value description
OK | Return value OK
Example

Command: device adc chavrratio set –sid=0 –value=2
Response: OK OK \r\n
Example description: | Set ADC averaging ratio 2 to stream with ID 0. Command returns OK to notify that everything is set successfully.

### 2.4.8. Get Analog input averaging ratio

Get analog input adc averaging ratio by utilizing system service.

Command name
device adc chavrratio get
Command Arguments
Key | Value description
-sid | Unique stream ID obtained by device stream create command

Return Value

<status><ws><averagingRatio><ws><eom>

Return arguments
Key | Value description
averagingRatio | Averaging ratio read from device
Example

Command: device adc chavrratio get –sid=0
Response: OK 128 \r\n
Example description: | Get ADC averaging ratio of stream with ID 0. Command returns averaging ratio to notify that everything is set successfully

### 2.4.9. Set Analog input sampling time

Set analog input adc sampling time by utilizing system service.

Command name
device adc stime set
Command Arguments
Key | Value description
-sid | Unique stream ID obtained by device stream create command
-value | Stream’s ADC sampling time {value} [us]
Return Value

<status><ws><OK><ws><eom>

Return arguments
Key | Value description
OK | Return value OK
Example

Command: device adc stime set –sid=0 –value=50
Response: OK OK \r\n
Example description: | Set ADC input sampling time 50 to stream with ID 0. Command returns OK to notify that everything is set successfully

### 2.4.10. Get Analog input sampling time

Get analog input sampling time by utilizing system service.

Command name
device adc stime get
Command Arguments
Key | Value description
-sid | Unique stream ID obtained by device stream create command

Return Value

<status><ws><samplingTime><ws><eom>

Return arguments
Key | Value description
samplingTime | Sampling time read from device
Example

Command: device adc stime get –sid=0
Response: OK 50 \r\n
Example description: | Get ADC input sampling time of stream with ID 0. Command returns sampling time to notify that everything is set successfully

### 2.4.11. Set Analog input voltage offset

Set analog input adc voltage offset by utilizing system service.

Command name
device adc chvoffset set
Command Arguments
Key | Value description
-sid | Unique stream ID obtained by device stream create command
-value | Stream’s ADC voltage offset {value} [mV]
Return Value

<status><ws><OK><ws><eom>

Return arguments
Key | Value description
OK | Return value OK
Example

Command: device adc chvoffset set –sid=0 –value=100
Response: OK OK \r\n
Example description: | Set ADC input voltage offset 100 to stream with ID 0. Command returns OK to notify that everything is set successfully

### 2.4.12. Get Analog input voltage offset

Get analog input adc voltage offset by utilizing system service.

Command name
device adc chvoffset get
Command Arguments
Key | Value description

Return Value

| <status><ws><voltageOffset><ws><eom>

Return arguments
Key | Value description
voltageOffset | Voltage offset read from device
Example

Command: device adc chvoffset get –sid=0
Response: OK 100 \r\n
Example description: | Get ADC input voltage offset of stream with ID 0. Command returns voltage offset to notify that everything is set successfully

### 2.4.13. Set Analog input current offset

Set analog input adc current offset by utilizing system service.

Command name
device adc chcoffset set
Command Arguments
Key | Value description
-sid | Unique stream ID obtained by device stream create command
-value | Stream’s ADC current offset {value} [mA]
Return Value

<status><ws><OK><ws><eom>

Return arguments
Key | Value description
OK | Return value OK
Example

Command: device adc chvoffset set –sid=0 –value=100
Response: OK OK \r\n
Example description: | Set ADC input current offset 100 to stream with ID 0. Command returns OK to notify that everything is set successfully

### 2.4.14. Get Analog input current offset

Get analog input adc current offset by utilizing system service.

Command name
device adc chcoffset get
Command Arguments
Key | Value description
-sid | Unique stream ID obtained by device stream create command

Return Value

<status><ws><currentOffset><ws><eom>

Return arguments
Key | Value description
currentOffset | Current offset read form device
Example

Command: device adc chcoffset get –sid=0
Response: OK 100 \r\n
Example description: | Get ADC input current offset of stream with ID 0. Command returns current offset to notify that everything is set successfully

### 2.4.15. Get Analog input clock

Get analog input adc clock by utilizing system service.

Command name
device adc clk get
Command Arguments
Key | Value description
-sid | Unique stream ID obtained by device stream create command

Return Value

<status><ws>< adcInputClk ><ws><eom>

Return arguments
Key | Value description
adcInputClk | Input Clock read form device
Example

Command: device adc clk get –sid=0
Response: OK 80000000 \r\n
Example description: | Get ADC input clock of stream with ID 0. Command returns input clock to notify that everything is set successfully

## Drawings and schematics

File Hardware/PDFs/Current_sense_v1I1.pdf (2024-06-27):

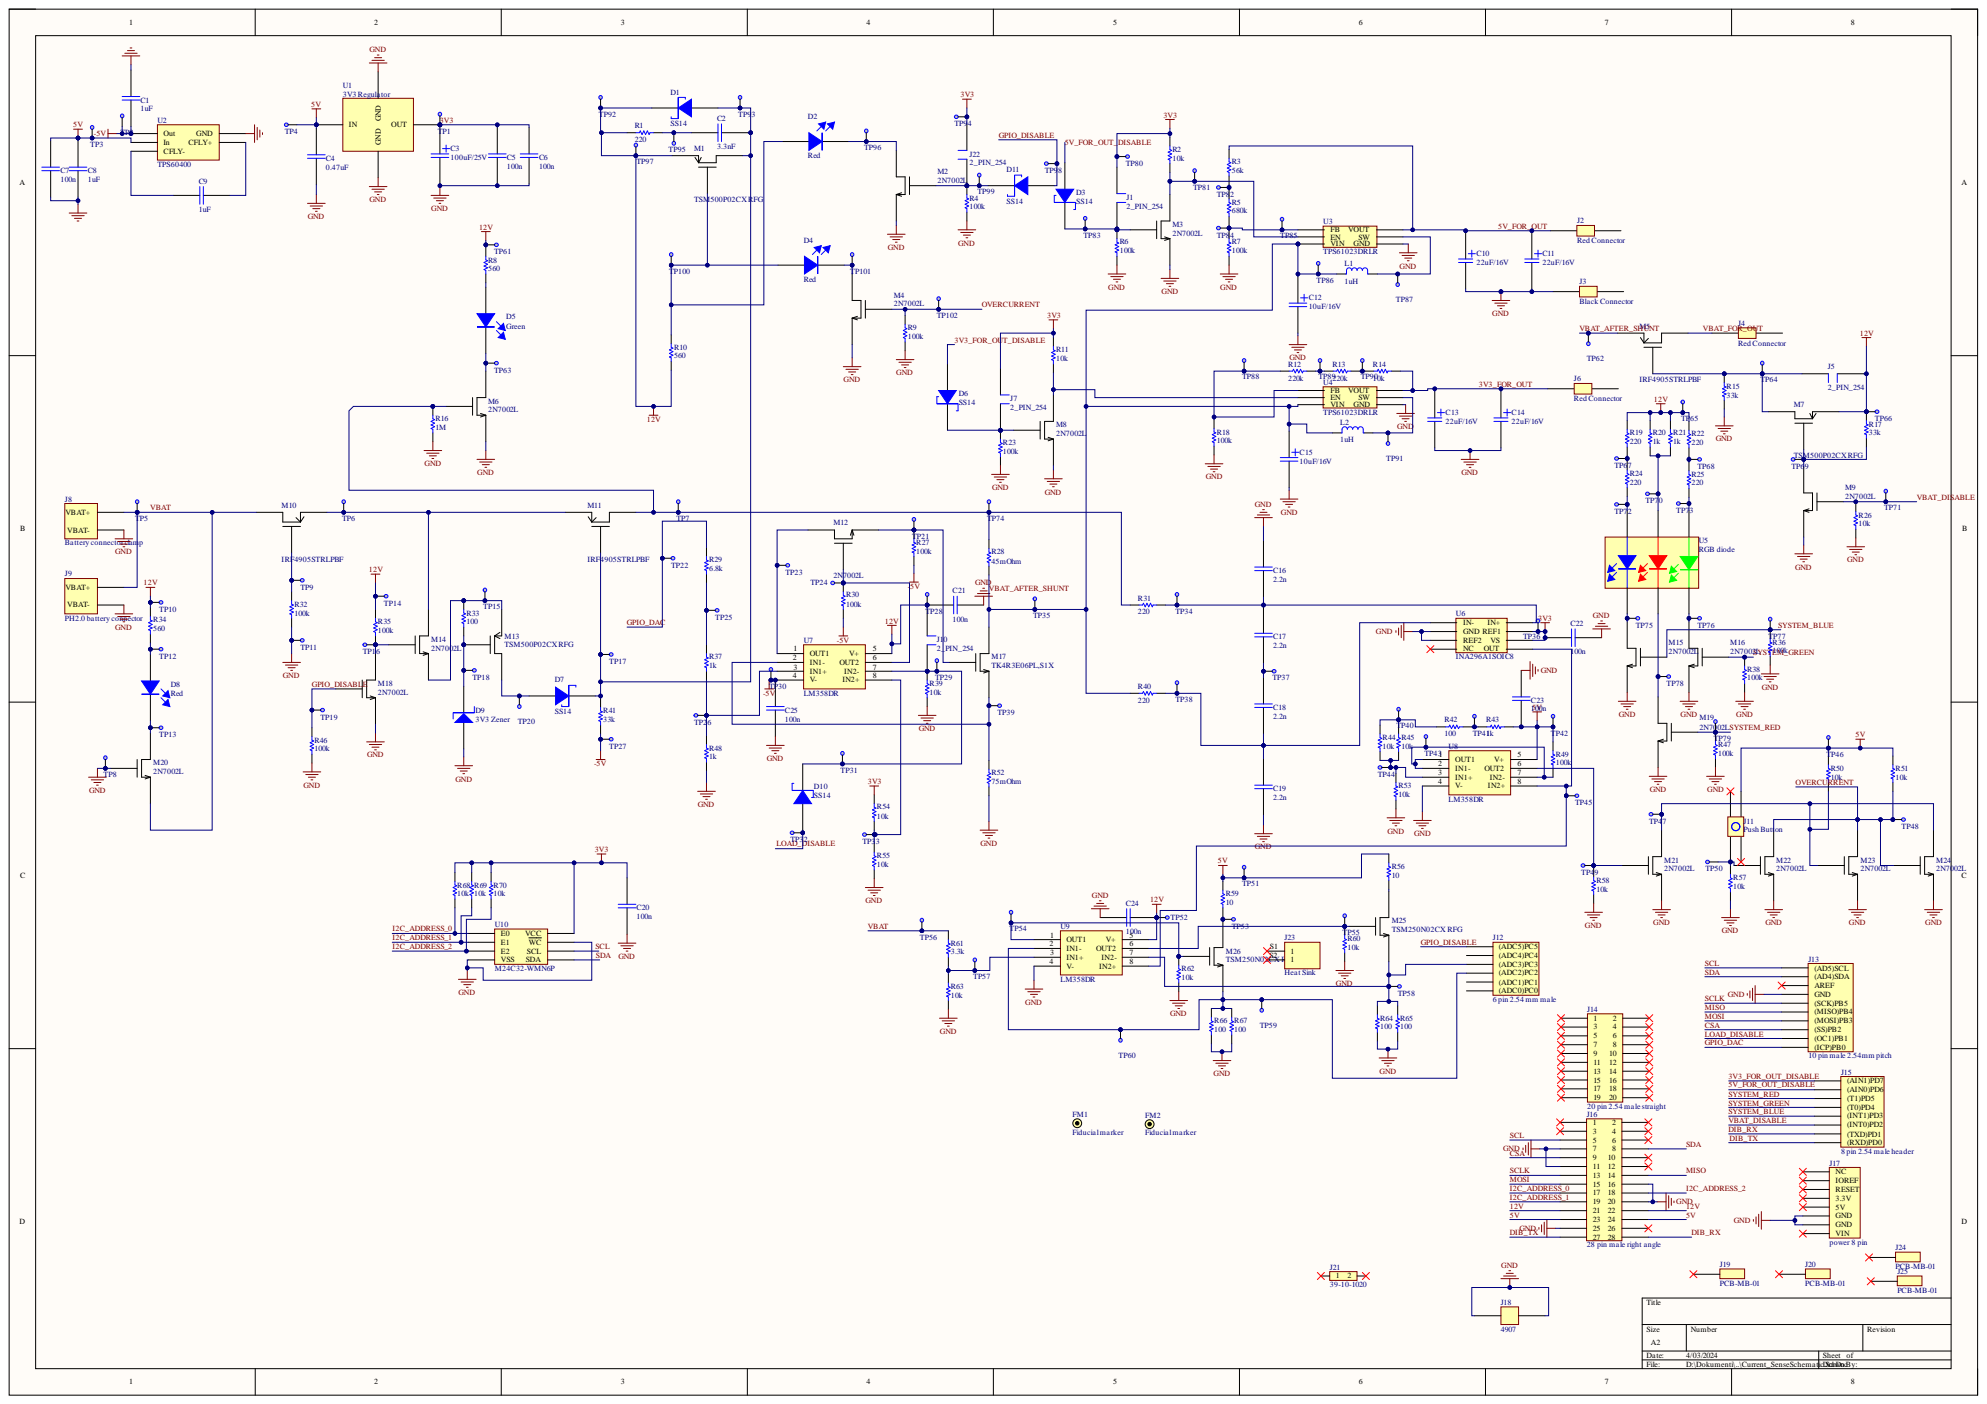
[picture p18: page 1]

TP64 2_PIN_254 M7

IN1+ 3
V- 4

1 2 3 4 5 6 7 8 9 10 11 12 13 14 15 16 17 18 19 20 21 22 23 24 25 26 27 28 | VBAT_DISABLE DIB_RX

28 pin male right angle

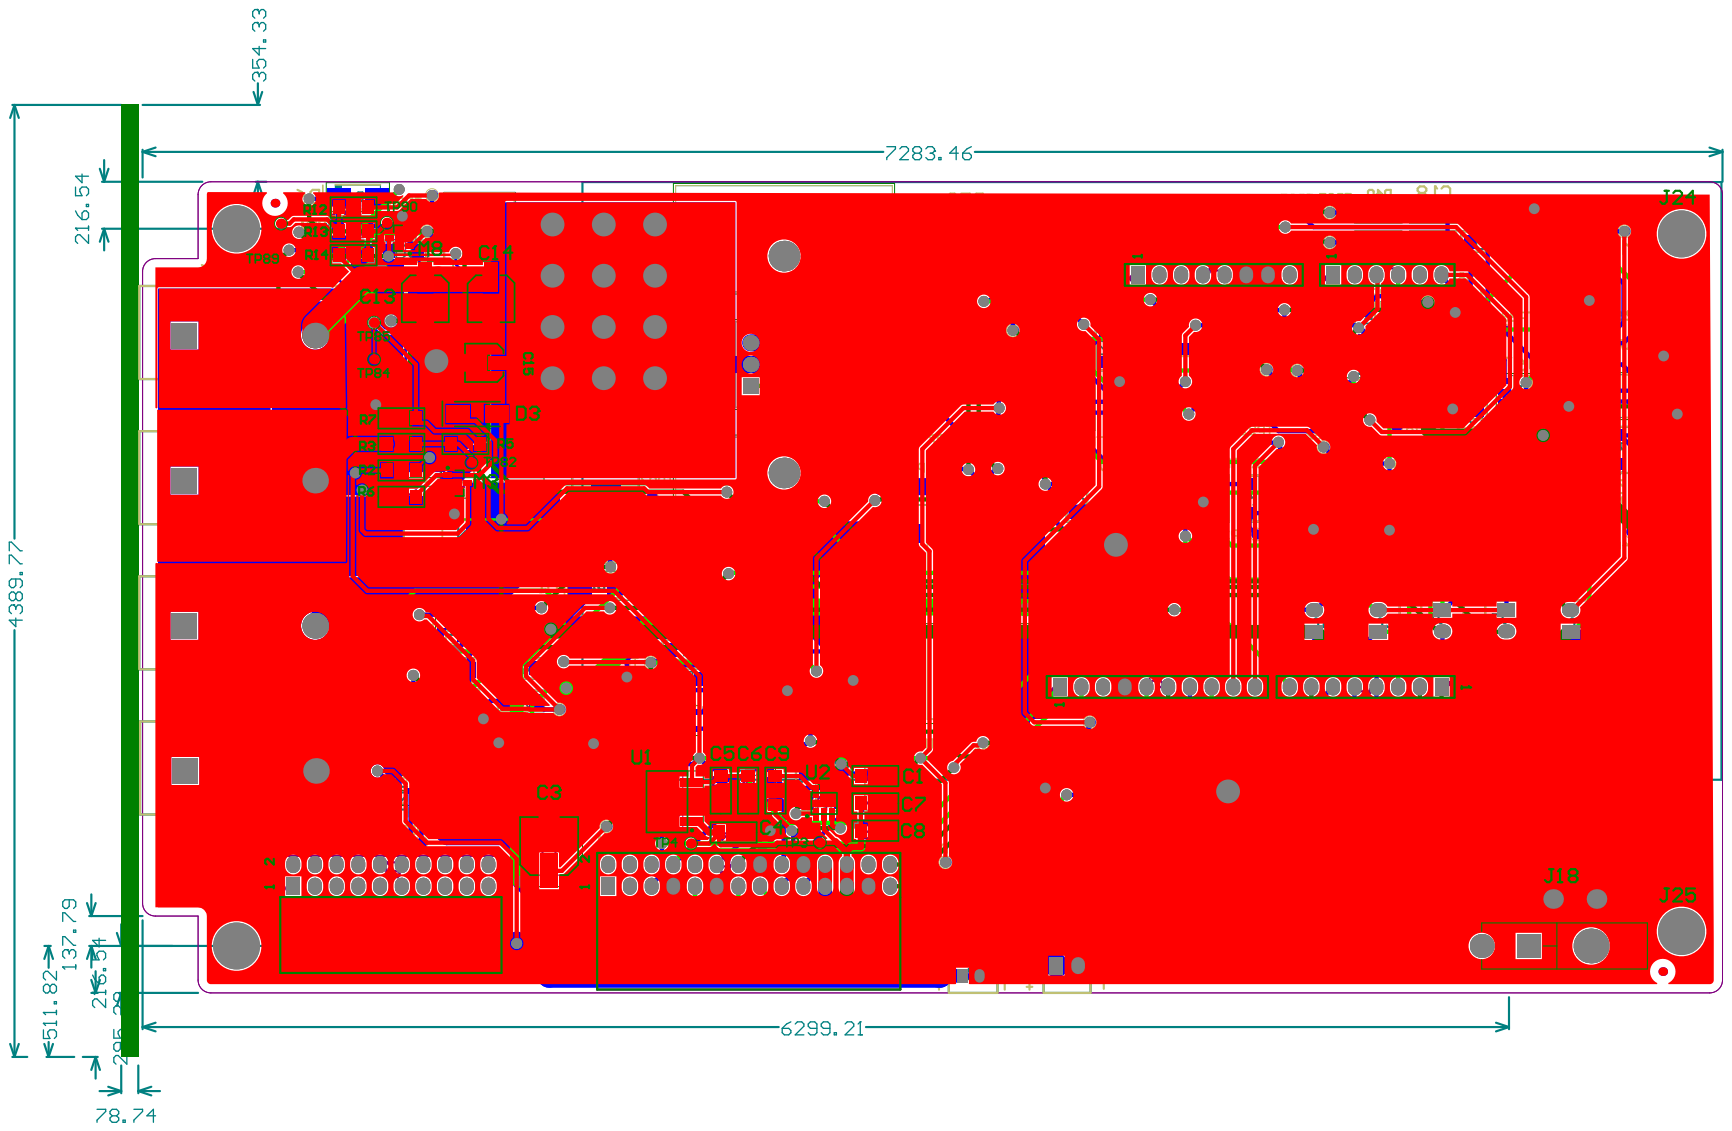
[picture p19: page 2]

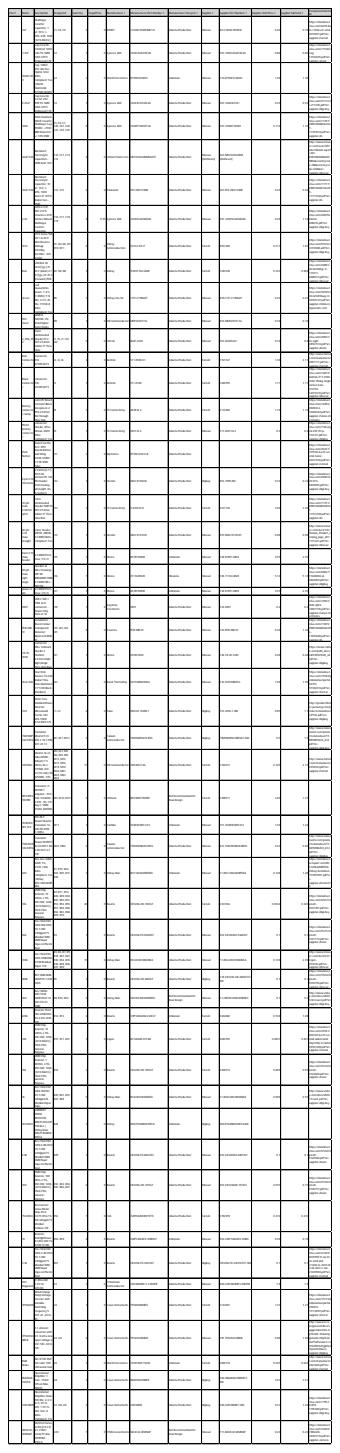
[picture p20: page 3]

3.3nF | Cap Ceramic 0.0033uF 100V C0G 1% SMD 1206 125°C Embossed T/R | C2 | 1 | 0 Kyocera AVX | 12061A332FAT2A | Volume Production | Mouser | 581-12061A332FAT2A | | 0.86 | https://datasheet.ciiva.com/11536/c 0.86 cog-11536655.pdf?src-supplier=Avnet

100uF/25 V | Cap, 100Uf, 25V, Alu Elec, Hybrid, Smd Rohs Compliant: Yes |Wurth Elektronik 875585344001 | C3 | 1 | 0 Wurth Electronics | 875585344001 | Unknown | Mouser | 710-875585344001 | | 1.39 | 1.39

0.47uF | Cap Ceramic 0.47uF 25V X7R 5% SMD 1206 125°C Embossed T/R | C4 | 1 | 0 Kyocera AVX | 12063C474JAT2A | Volume Production | Mouser | 581-12063C474J | | 0.43 | https://datasheet.ciiva.com/211/cx7 0.43 r-211340.pdf?src-supplier=Digi-Key

100n | 1206 Standard 100nF Ceramic Multilayer Cap; 50VDC; +150C; X8R Dielectric; +/-10% SMD | C5, C6, C7, C20, C21, C22, C23, C24, C25 | 9 | 0 Kyocera AVX | 12065F104K4T2A | Volume Production | Mouser | 581-12065F104K4 | 0.172 | | https://datasheet.ciiva.com/11787/0900766b80def34 1.72 7-11787814.pdf?src-supplier=Rs

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

10uF/16V | Aluminum Electrolytic Capacitor, 10 uF, 16 V, ± 20%, 1000 hours @ 105°C, Radial Can -SMD | C12, C15 | 2 | 0 Panasonic | EEE-HA1C100R | Volume Production | Mouser | 667-EEE-HA1C100R | | 0.23 | https://datasheet.ciiva.com/11777/0.46 0900766b8102e3f 9-11777432.pdf?src-supplier=Rs

2.2n | 1206 2.2 nF 50V ±10 % Tolerance X7R Surface Mount Multilayer Ceramic Capacitor | C16, C17, C18, C19 | 4 | 0.29 Kyocera AVX | 12065C222KAZ2A | Volume Production | Mouser | 581-12065C222KAZ2A | | 0.29 | https://datasheet.ciiva.com/208/fle 1.16 xiterm-208276.pdf?src-supplier=Digi-Key

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

Red | LED Red 20 mcd (Typ.) @ 25 C (Axial) 2.1 V (Typ.) @ 25 C (Forward) PCB | D2, D4, D8 | 3 | 0 Vishay | TLMS1100-GS08 | Volume Production | Farnell | 1440338 | 0.323 | 0.969 | https://datasheet.ciiva.com/4689/s ml-lxl1206gc-tr-115211-4689614.pdf?src-supplier=Mouser

Green | Led, Quasarbrite, Green, T-3/4 (1.8Mm), 574 Nm, 2.2 V, 20 Ma, 170 Mcd Rohs Compliant: Yes | D5 | 1 | 0 Vishay Lite-On | LTST-C190GKT | Volume Production | Mouser | 859-LTST-C190GKT | | 0.23 | https://datasheet.ciiva.com/30105/s 0.23 ml-lxl1209sugc-tr-30105147.pdf?src-supplier=Onlineco mponents.com

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

2_PIN_25 4 | Conn Unshrouded Header PL 2 POS 2.54mm Solder ST Thru-Hole | J1, J5, J7, J10, J22 | 5 | 0 Omron | XG8T-0241 | Volume Production | Mouser | 653-XG8T0241 | | 0.16 | https://datasheet.ciiva.com/48561/0.8 en-xg8t-48561514.pdf?src-supplier=Avnet

Red Connecto r | Connector, Pcb, 2CONTACTS | J2, J4, J6 | 3 | 0 Deltron | 571-0500-01 | Volume Production | Farnell | 1101127 | | 1.39 | 4.17 http://www.farnell.com/datasheets/2007771.pdf?src-supplier=Farnell

Black Connecto r | Connector, Pcb, 2CONTACTS | J3 | 1 | 0 Deltron | 571-0100 | Volume Production | Farnell | 1494595 | | 1.17 | https://datasheet.ciiva.com/12074/1.17 deltron-571-0100-4mm-90deg-single-socket-data-372703-12074316.pdf?src-supplier=Mouser

Battery connecto r clamp | Conn PC Board Terminal Block Receptacle 2 POS 2.54mm RA Through Hole 10A | J8 | 1 | 0 TE Connectivity | 282834-2 | Volume Production | Farnell | 2112482 | | 1.19 | https://datasheet.ciiva.com/16386/1.19 282834-2-16386363.pdf?src-supplier=Future+El ectronics

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

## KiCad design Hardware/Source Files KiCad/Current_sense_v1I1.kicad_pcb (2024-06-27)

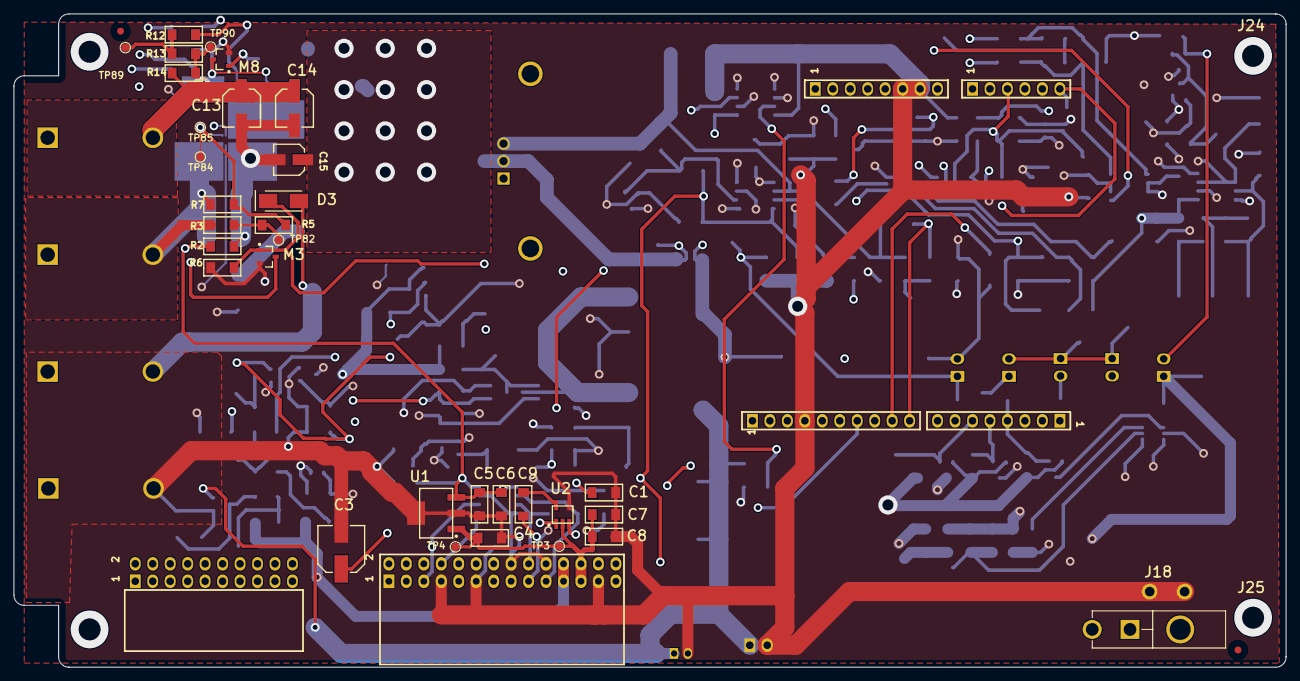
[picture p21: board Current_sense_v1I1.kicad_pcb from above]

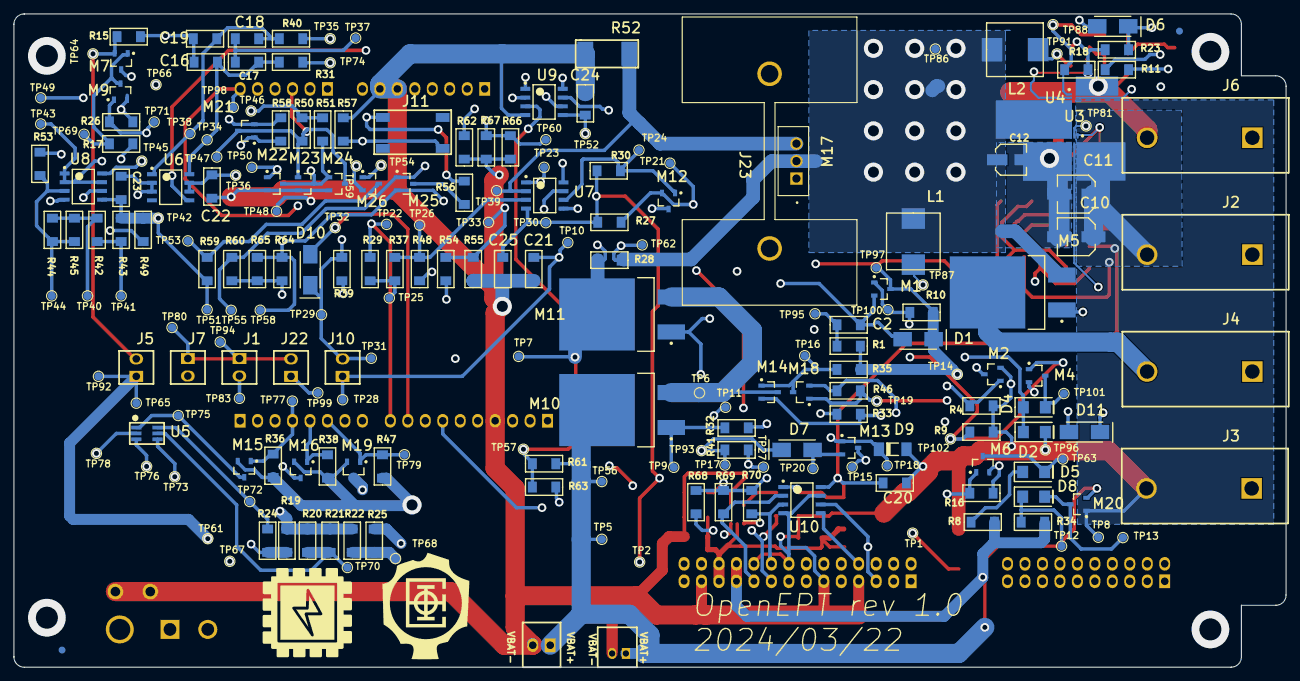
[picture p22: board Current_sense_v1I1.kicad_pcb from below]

Board: 4 copper layers, 185.0 x 95.0 mm, 273 parts (228 on the bottom side), 97 nets.

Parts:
C1, C8, C9: 1uF; 1206Capacitor
C2: 3.3nF; 1206Capacitor
C3: 100uF/25V; CAPAE7366X60N
C4: 0.47uF; 1206Capacitor
C5, C6, C7, C20, C21, C22, C23, C24, C25: 100n; 1206Capacitor
C10, C11, C13, C14: 22uF/16V
C12, C15: 10uF/16V; 10uF/16V Electrolytic
C16, C17, C18, C19: 2.2n; 1206Capacitor
D1, D3, D6, D7, D10, D11: SS14; DIOM5026X23N
D2, D4, D8: Red; RED
D5: Green; GREEN
D9: 3V3 Zener; DIOMELF3515N
FM1, FM2: Fiducial marker; Fiducal Marker
J1, J5, J7, J10, J22: 2_PIN_254; 2_PIN_2.54mm
J2, J4, J6: Red Connector; RED CONNECTOR
J3: Black Connector; BLACK CONNECTOR
J8: Battery connector clamp; 2.54mm CLAMP connector
J9: PH2.0 battery connector; PH2.0 connector
J11: Push Button; PUSH_BUTTON
J12: 6 pin 2.54 mm male; 6_pin_header_male_2_54
J13: 10 pin male 2.54mm pitch; 10_pin_header_male_2_54
J14: 20 pin 2.54 male straight; 20_pin_header_angled_female_2_54_mm
J15: 8 pin 2.54 male header; 8_pin_header_male_2_54
J16: 28 pin male right angle; 28_PIN_HEADER_RIGHT_ANGLE
J17: power 8 pin; 8_pin_header_male_2_54
J18: 4907; 4907_FOOTPRINT
J19, J20, J24, J25: PCB-MB-01
J21: 39-10-1020; 39-30-1020
J23: Heat Sink; HEAT_SINK
L1, L2: 1uH; PA4333_7.4x6.8x3.2mm
M1, M7, M13: TSM500P02CX RFG; SOT95P240X100-3N
M2, M3, M4, M6, M8, M9, M12, M14, M15, M16, M18, M19, M20, M21, M22, M23, M24: 2N7002L; SOT95P240X100-3N
M5, M10, M11: IRF4905STRLPBF; DPAK254P1524X483-3L
M17: TK4R3E06PL,S1X; TO-220-3
M25, M26: TSM250N02CX RFG; SOT95P240X100-3N
R1, R19, R22, R24, R25, R31, R40: 220; RESISTOR1206
R2, R11, R14, R26, R39, R44, R45, R50, R51, R53, R54, R55, R57, R58, R60, R62, R63, R68, R69, R70: 10k; RESISTOR1206
R3: 56k; RESISTOR1206
R4, R6, R7, R9, R18, R23, R27, R30, R32, R35, R36, R38, R46, R47, R49: 100k; RESISTOR1206
R5: 680k; RESISTOR1206
R8, R10, R34: 560; RESISTOR1206
R12, R13: 220k; RESISTOR1206
R15, R17, R41: 33k; RESISTOR1206
R16: 1M; RESISTOR1206
R20, R21, R37, R43, R48: 1k; RESISTOR1206
R28: 45mOhm; RESISTOR1206
R29: 6.8k; RESISTOR1206
R33, R42, R64, R65, R66, R67: 100; RESISTOR1206
R52: 75mOhm; RESISTOR2512
R56, R59: 10; RESISTOR1206
R61: 3.3k; RESISTOR1206
TP1, TP2, TP3, TP4, TP5, TP6, TP7, TP8, TP9, TP10, TP11, TP12, TP13, TP14, TP15, TP16, TP17, TP18, TP19, TP20, TP21, TP22, TP23, TP24, TP25, TP26, TP27, TP28, TP29, TP30, TP31, TP32, TP33, TP34, TP35, TP36, TP37, TP38, TP39, TP40, TP41, TP42, TP43, TP44, TP45, TP46, TP47, TP48, TP49, TP50, TP51, TP52, TP53, TP54, TP55, TP56, TP57, TP58, TP59, TP60, TP61, TP62, TP63, TP64, TP65, TP66, TP67, TP68, TP69, TP70, TP71, TP72, TP73, TP74, TP75, TP76, TP77, TP78, TP79, TP80, TP81, TP82, TP83, TP84, TP85, TP86, TP87, TP88, TP89, TP90, TP91, TP92, TP93, TP94, TP95, TP96, TP97, TP98, TP99, TP100, TP101, TP102: TestPoint
U1: 3V3 Regulator; SOT230P700X180-4N
U2: TPS60400; SOT95P280X135-5N
U3, U4: TPS61023DRLR; SOT563
U5: RGB diode; RGBDIODE
U6: INA296A1SOIC8; SOIC127P600X175-8N
U7, U8, U9: LM358DR; SOIC127P600X175-8N
U10: M24C32-WMN6P; SOIC127P600X175-8N

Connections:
3V3: C3.1, C5.2, C6.2, C20.2, C22.1, J1.1, J7.1, J22.2, R2.2, R11.2, R54.2, R68.2, R69.2, R70.2, TP1.1, TP36.1, TP80.1, TP94.1, U1.3, U6.6, U6.7, U10.8
3V3_FOR_OUT: C13.1, C14.1, J6.2, R14.2, U4.6
3V3_FOR_OUT_DISABLE: D6.1, J15.8
5V: C4.2, C7.2, C8.2, C23.1, J11.4, J16.23, J16.24, R43.1, R49.2, R50.2, R51.2, R56.2, R59.2, TP3.1, TP4.1, TP42.1, TP46.1, TP51.1, U1.1, U2.2, U8.5
5V_FOR_OUT: C10.1, C11.1, J2.2, R3.2, U3.6
5V_FOR_OUT_DISABLE: D3.1, J15.7
12V: C21.2, C24.2, D1.2, J5.1, J10.1, J16.21, J16.22, M1.3, M7.3, R1.1, R8.2, R10.1, R17.2, R19.2, R20.2, R21.2, R22.2, R34.2, R35.2, TP10.1, TP14.1, TP28.1, TP52.1, TP61.1, TP65.1, TP66.1, TP92.1, TP97.1, U7.5, U9.5
-5V: C1.1, C25.2, R27.1, R30.1, R41.1, TP2.1, TP27.1, TP30.1, U2.1, U7.4
CSA: J13.8, J16.9
DIB_RX: J15.2, J16.28
DIB_TX: J15.1, J16.27
GND: C1.2, C3.2, C4.1, C5.1, C6.1, C7.1, C8.1, C10.2, C11.2, C12.2, C13.2, C14.2, C15.2, C16.2, C19.1, C20.1, C21.1, C22.2, C23.2, C24.1, C25.1, D9.1, J3.2, J8.2, J9.2, J13.4, J16.7, J16.11, J16.16, J16.20, J16.25, J17.6, J17.7, J18.1, J18.2, M2.2, M3.2, M4.2, M6.2, M8.2, M9.2, M15.2, M16.2, M18.2, M19.2, M20.1, M21.2, M22.2, M23.2, M24.2, R4.1, R6.1, R7.1, R9.1, R15.1, R16.1, R18.1, R23.1, R26.1, R32.1, R36.1, R38.1, R39.1, R46.1, R47.1, R48.1, R52.1, R53.1, R55.1, R57.1, R58.1, R60.1, R62.1, R63.1, R64.1, R65.1, R66.1, R67.1, TP8.1, TP11.1, U1.2, U1.4, U2.4, U3.4, U4.4, U6.2, U6.3, U8.4, U9.4, U10.4, U10.7
GPIO_DAC: J13.10, R29.2, TP22.1
GPIO_DISABLE: D11.1, J12.6, M18.1, R46.2, TP19.1, TP98.1
I2C_ADDRESS_0: J16.17, R68.1, U10.1
I2C_ADDRESS_1: J16.19, R69.1, U10.2
I2C_ADDRESS_2: J16.18, R70.1, U10.3
LOAD_DISABLE: D10.1, J13.9, TP32.1
MISO: J13.6, J16.14
MOSI: J13.7, J16.15
NetC2_1: C2.1, R1.2, TP95.1
NetC2_2: C2.2, D1.1, D7.2, M1.2, M11.1, R41.2, TP17.1, TP93.1
NetC9_1: C9.1, U2.3
NetC9_2: C9.2, U2.5
NetC16_1: C16.1, C17.2, R31.2, TP34.1, U6.8
NetC17_1: C17.1, C18.2, TP37.1
NetC18_1: C18.1, C19.2, R40.2, TP38.1, U6.1
NetD2_1: D2.1, M2.3, TP96.1
NetD2_2: D2.2, D4.2, M1.1, R10.2, TP100.1
NetD3_2: D3.2, J1.2, M3.1, R6.2, TP83.1
NetD4_1: D4.1, M4.3, TP101.1
NetD5_1: D5.1, M6.3, TP63.1
NetD5_2: D5.2, R8.1
NetD6_2: D6.2, J7.2, M8.1, R23.2
NetD7_1: D7.1, M13.2, TP20.1
NetD8_1: D8.1, M20.3, TP13.1
NetD8_2: D8.2, R34.1, TP12.1
NetD9_2: D9.2, M13.1, R33.1, TP18.1
NetD10_2: D10.2, J10.2, R39.2, TP29.1, TP31.1, U7.7
NetD11_2: D11.2, J22.1, M2.1, R4.2, TP99.1
NetJ5_2: J5.2, M5.1, M7.2, R15.2, TP64.1
NetJ11_1: J11.1, M22.1, R57.2, TP50.1
NetJ12_3: J12.3, M26.2, R66.2, R67.2, TP59.1, TP60.1, U9.2
NetJ12_4: J12.4, M25.2, R64.2, R65.2, TP58.1, U9.7
NetL1_2: L1.2, TP87.1, U3.5
NetL2_2: L2.2, TP91.1, U4.5
NetM3_3: M3.3, R2.1, TP81.1, U3.2
NetM6_1: M6.1, M11.4, R16.2, R28.2, R31.1, TP7.1, TP74.1
NetM7_1: M7.1, M9.3, R17.1, TP69.1
NetM8_3: M8.3, R11.1, U4.2
NetM10_1: M10.1, R32.2, TP9.1
NetM10_3: M10.3, M11.3, M14.3, TP6.1
NetM12_1: M12.1, R30.2, TP24.1, U7.6
NetM12_2: M12.2, M17.1, R27.2, TP21.1
NetM12_3: M12.3, TP23.1, U7.1
NetM13_3: M13.3, M14.2, R33.2, TP15.1
NetM14_1: M14.1, M18.3, R35.1, TP16.1
NetM15_3: M15.3, TP75.1, U5.1
NetM16_3: M16.3, TP76.1, U5.5
NetM17_3: M17.3, R52.2, TP39.1, U7.2
NetM19_3: M19.3, TP78.1, U5.3
NetM21_1: M21.1, R58.2, TP49.1, U8.6
NetM21_3: M21.3, M23.1, M24.3, R50.1, TP47.1
NetM25_1: M25.1, R60.2, TP55.1, U9.6
NetM25_3: M25.3, R56.1
NetM26_1: M26.1, R62.2, TP54.1, U9.1
NetM26_3: M26.3, R59.1, TP53.1
NetR3_1: R3.1, R5.2, TP82.1
NetR5_1: R5.1, R7.2, TP84.1, TP85.1, U3.1
NetR12_1: R12.1, R18.2, TP88.1, U4.1
NetR12_2: R12.2, R13.1, TP89.1
NetR13_2: R13.2, R14.1, TP90.1
NetR19_1: R19.1, R24.2, TP67.1
NetR20_1: R20.1, R21.1, TP70.1, U5.4
NetR22_1: R22.1, R25.2, TP68.1
NetR24_1: R24.1, TP72.1, U5.2
NetR25_1: R25.1, TP73.1, U5.6
NetR29_1: R29.1, R37.2, TP25.1
NetR37_1: R37.1, R48.2, TP26.1, U7.3
NetR42_1: R42.1, R44.2, R45.2, TP40.1
NetR42_2: R42.2, R43.2, TP41.1
NetR44_1: R44.1, R45.1, R53.2, TP44.1, U8.3
NetR49_1: R49.1, TP43.1, U8.1, U8.2, U8.7
NetR54_1: R54.1, R55.2, TP33.1, U7.8
NetR61_1: R61.1, R63.2, TP57.1, U9.3
NetTP45_1: TP45.1, U6.5, U8.8, U9.8
OVERCURRENT: M4.1, M22.3, M23.3, M24.1, R9.2, R51.1, TP48.1, TP102.1
SCL: J13.1, J16.5, U10.6
SCLK: J13.5, J16.13
SDA: J13.2, J16.8, U10.5
SYSTEM_BLUE: J15.4, M15.1, R36.2, TP77.1
SYSTEM_GREEN: J15.5, M16.1, R38.2
SYSTEM_RED: J15.6, M19.1, R47.2, TP79.1
VBAT: J8.1, J9.1, M10.4, M20.2, R61.2, TP5.1, TP56.1
VBAT_AFTER_SHUNT: C12.1, C15.1, L1.1, L2.1, M5.3, M17.2, R28.1, R40.1, TP35.1, TP62.1, TP86.1, U3.3, U4.3
VBAT_DISABLE: J15.3, M9.1, R26.2, TP71.1
VBAT_FOR_OUT: J4.2, M5.4

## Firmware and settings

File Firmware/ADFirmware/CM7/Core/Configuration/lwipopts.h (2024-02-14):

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

/* Define to prevent recursive inclusion --------------------------------------*/
#ifndef __LWIPOPTS__H__
#define __LWIPOPTS__H__

#include "main.h"

/*-----------------------------------------------------------------------------*/
/* Current version of LwIP supported by CubeMx: 2.1.2 -*/
/*-----------------------------------------------------------------------------*/

/* Within 'USER CODE' section, code will be kept by default at each generation */
#ifdef __cplusplus
 extern "C" {
#endif

/* STM32CubeMX Specific Parameters (not defined in opt.h) ---------------------*/
/* Parameters set in STM32CubeMX LwIP Configuration GUI -*/
/*----- WITH_RTOS enabled (Since FREERTOS is set) -----*/
#define WITH_RTOS 1
/*----- CHECKSUM_BY_HARDWARE enabled -----*/
#define CHECKSUM_BY_HARDWARE 1
/*-----------------------------------------------------------------------------*/

/* LwIP Stack Parameters (modified compared to initialization value in opt.h) -*/
/* Parameters set in STM32CubeMX LwIP Configuration GUI -*/
/*----- Default value in ETH configuration GUI in CubeMx: 1524 -----*/
#define ETH_RX_BUFFER_SIZE 1524
/*----- Value in opt.h for MEM_ALIGNMENT: 1 -----*/
#define MEM_ALIGNMENT 4
/*----- Default Value for MEM_SIZE: 1600 ---*/
#define MEM_SIZE 131048
/*----- Default Value for H7 devices: 0x30044000 -----*/
#define LWIP_RAM_HEAP_POINTER 0x30020000
/*----- Value supported for H7 devices: 1 -----*/
#define LWIP_SUPPORT_CUSTOM_PBUF 1
/*----- Value in opt.h for LWIP_ETHERNET: LWIP_ARP || PPPOE_SUPPORT -*/
#define LWIP_ETHERNET 1
/*----- Default Value for LWIP_BROADCAST_PING: 0 ---*/
#define LWIP_BROADCAST_PING 1
/*----- Default Value for LWIP_MULTICAST_PING: 0 ---*/
#define LWIP_MULTICAST_PING 1
/*----- Value in opt.h for LWIP_DNS_SECURE: (LWIP_DNS_SECURE_RAND_XID | LWIP_DNS_SECURE_NO_MULTIPLE_OUTSTANDING | LWIP_DNS_SECURE_RAND_SRC_PORT) -*/
#define LWIP_DNS_SECURE 7
/*----- Value in opt.h for TCP_SND_QUEUELEN: (4*TCP_SND_BUF + (TCP_MSS - 1))/TCP_MSS -----*/
#define TCP_SND_QUEUELEN 9
/*----- Value in opt.h for TCP_SNDLOWAT: LWIP_MIN(LWIP_MAX(((TCP_SND_BUF)/2), (2 * TCP_MSS) + 1), (TCP_SND_BUF) - 1) -*/
#define TCP_SNDLOWAT 1071
/*----- Value in opt.h for TCP_SNDQUEUELOWAT: LWIP_MAX(TCP_SND_QUEUELEN)/2, 5) -*/
#define TCP_SNDQUEUELOWAT 5
/*----- Value in opt.h for TCP_WND_UPDATE_THRESHOLD: LWIP_MIN(TCP_WND/4, TCP_MSS*4) -----*/
#define TCP_WND_UPDATE_THRESHOLD 536
/*----- Value in opt.h for LWIP_NETIF_LINK_CALLBACK: 0 -----*/
#define LWIP_NETIF_LINK_CALLBACK 1
/*----- Value in opt.h for TCPIP_THREAD_STACKSIZE: 0 -----*/
#define TCPIP_THREAD_STACKSIZE 4096
/*----- Value in opt.h for TCPIP_THREAD_PRIO: 1 -----*/
#define TCPIP_THREAD_PRIO 24
/*----- Value in opt.h for TCPIP_MBOX_SIZE: 0 -----*/
#define TCPIP_MBOX_SIZE 20
/*----- Value in opt.h for SLIPIF_THREAD_STACKSIZE: 0 -----*/
#define SLIPIF_THREAD_STACKSIZE 1024
/*----- Value in opt.h for SLIPIF_THREAD_PRIO: 1 -----*/
#define SLIPIF_THREAD_PRIO 3
/*----- Value in opt.h for DEFAULT_THREAD_STACKSIZE: 0 -----*/
#define DEFAULT_THREAD_STACKSIZE 1024
/*----- Value in opt.h for DEFAULT_THREAD_PRIO: 1 -----*/
#define DEFAULT_THREAD_PRIO 10
/*----- Value in opt.h for DEFAULT_UDP_RECVMBOX_SIZE: 0 -----*/
#define DEFAULT_UDP_RECVMBOX_SIZE 6
/*----- Value in opt.h for DEFAULT_TCP_RECVMBOX_SIZE: 0 -----*/
#define DEFAULT_TCP_RECVMBOX_SIZE 6
/*----- Value in opt.h for DEFAULT_ACCEPTMBOX_SIZE: 0 -----*/
#define DEFAULT_ACCEPTMBOX_SIZE 6
/*----- Value in opt.h for RECV_BUFSIZE_DEFAULT: INT_MAX -----*/
#define RECV_BUFSIZE_DEFAULT 2000000000
/*----- Default Value for LWIP_PERF: 0 ---*/
#define LWIP_PERF 1
/*----- Value in opt.h for LWIP_STATS: 1 -----*/
#define LWIP_STATS 0
/*----- Value in opt.h for CHECKSUM_GEN_IP: 1 -----*/
#define CHECKSUM_GEN_IP 0
/*----- Value in opt.h for CHECKSUM_GEN_UDP: 1 -----*/
#define CHECKSUM_GEN_UDP 0
/*----- Value in opt.h for CHECKSUM_GEN_TCP: 1 -----*/
#define CHECKSUM_GEN_TCP 0
/*----- Value in opt.h for CHECKSUM_GEN_ICMP6: 1 -----*/
#define CHECKSUM_GEN_ICMP6 0
/*----- Value in opt.h for CHECKSUM_CHECK_IP: 1 -----*/
#define CHECKSUM_CHECK_IP 0
/*----- Value in opt.h for CHECKSUM_CHECK_UDP: 1 -----*/
#define CHECKSUM_CHECK_UDP 0
/*----- Value in opt.h for CHECKSUM_CHECK_TCP: 1 -----*/
#define CHECKSUM_CHECK_TCP 0
/*----- Value in opt.h for CHECKSUM_CHECK_ICMP6: 1 -----*/
#define CHECKSUM_CHECK_ICMP6 0
/*-----------------------------------------------------------------------------*/
/* USER CODE BEGIN 1 */

#define LWIP_TCP			1
#define LWIP_CALLBACK_API	1
#define MEMP_NUM_TCP_PCB	10
#define LWIP_SO_RCVTIMEO	1
/* USER CODE END 1 */

#ifdef __cplusplus
}
#endif
#endif /*__LWIPOPTS__H__ */

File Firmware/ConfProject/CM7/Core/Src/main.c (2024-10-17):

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
/* Includes ------------------------------------------------------------------*/
#include "main.h"
#include "cmsis_os.h"
#include "lwip.h"

/* USER CODE BEGIN PD */

#ifndef HSEM_ID_0
#define HSEM_ID_0 (0U) /* HW semaphore 0*/
#endif

/* USER CODE END PD */

ADC_HandleTypeDef hadc3;
DMA_HandleTypeDef hdma_adc3;

DAC_HandleTypeDef hdac1;

SPI_HandleTypeDef hspi3;
SPI_HandleTypeDef hspi4;
SPI_HandleTypeDef hspi5;
DMA_HandleTypeDef hdma_spi4_rx;
DMA_HandleTypeDef hdma_spi5_rx;

TIM_HandleTypeDef htim1;
TIM_HandleTypeDef htim2;
TIM_HandleTypeDef htim3;
TIM_HandleTypeDef htim4;
TIM_HandleTypeDef htim5;
TIM_HandleTypeDef htim8;

UART_HandleTypeDef huart1;
UART_HandleTypeDef huart3;
UART_HandleTypeDef huart6;

/* Definitions for defaultTask */
osThreadId_t defaultTaskHandle;
const osThreadAttr_t defaultTask_attributes = {
  .name = "defaultTask",
  .stack_size = 256 * 4,
  .priority = (osPriority_t) osPriorityNormal,
};
void SystemClock_Config(void);
void PeriphCommonClock_Config(void);
static void MPU_Initialize(void);
static void MPU_Config(void);
static void MX_GPIO_Init(void);
static void MX_BDMA_Init(void);
static void MX_DMA_Init(void);
static void MX_USART3_UART_Init(void);
static void MX_DAC1_Init(void);
static void MX_ADC3_Init(void);
static void MX_TIM1_Init(void);
static void MX_USART1_UART_Init(void);
static void MX_USART6_UART_Init(void);
static void MX_TIM2_Init(void);
static void MX_SPI3_Init(void);
static void MX_TIM3_Init(void);
static void MX_TIM8_Init(void);
static void MX_TIM4_Init(void);
static void MX_TIM5_Init(void);
static void MX_SPI4_Init(void);
static void MX_SPI5_Init(void);
void StartDefaultTask(void *argument);

/**
  * @brief  The application entry point.
  * @retval int
  */
int main(void)
{
/* USER CODE BEGIN Boot_Mode_Sequence_0 */
  int32_t timeout;
/* USER CODE END Boot_Mode_Sequence_0 */

  /* Enable I-Cache---------------------------------------------------------*/
  SCB_EnableICache();

  /* Enable D-Cache---------------------------------------------------------*/
  SCB_EnableDCache();

/* USER CODE BEGIN Boot_Mode_Sequence_1 */
  /* Wait until CPU2 boots and enters in stop mode or timeout*/
  timeout = 0xFFFF;
  while((__HAL_RCC_GET_FLAG(RCC_FLAG_D2CKRDY) != RESET) && (timeout-- > 0));
//  if ( timeout < 0 )
//  {
//  Error_Handler();
//  }
/* USER CODE END Boot_Mode_Sequence_1 */
  /* MCU Configuration--------------------------------------------------------*/

  /* Reset of all peripherals, Initializes the Flash interface and the Systick. */
  HAL_Init();

  /* MPU Configuration--------------------------------------------------------*/
  MPU_Config();

  /* Configure the system clock */
  SystemClock_Config();

/* Configure the peripherals common clocks */
  PeriphCommonClock_Config();
/* USER CODE BEGIN Boot_Mode_Sequence_2 */
/* When system initialization is finished, Cortex-M7 will release Cortex-M4 by means of
HSEM notification */
/*HW semaphore Clock enable*/
__HAL_RCC_HSEM_CLK_ENABLE();
/*Take HSEM */
HAL_HSEM_FastTake(HSEM_ID_0);
/*Release HSEM in order to notify the CPU2(CM4)*/
HAL_HSEM_Release(HSEM_ID_0,0);
/* wait until CPU2 wakes up from stop mode */
timeout = 0xFFFF;
while((__HAL_RCC_GET_FLAG(RCC_FLAG_D2CKRDY) == RESET) && (timeout-- > 0));
if ( timeout < 0 )
{
Error_Handler();
}
/* USER CODE END Boot_Mode_Sequence_2 */

  /* Initialize all configured peripherals */
  MX_GPIO_Init();
  MX_BDMA_Init();
  MX_DMA_Init();
  MX_USART3_UART_Init();
  MX_DAC1_Init();
  MX_ADC3_Init();
  MX_TIM1_Init();
  MX_USART1_UART_Init();
  MX_USART6_UART_Init();
  MX_TIM2_Init();
  MX_SPI3_Init();
  MX_TIM3_Init();
  MX_TIM8_Init();
  MX_TIM4_Init();
  MX_TIM5_Init();
  MX_SPI4_Init();
  MX_SPI5_Init();
  /* Init scheduler */
  osKernelInitialize();

  /* USER CODE BEGIN RTOS_MUTEX */
  /* add mutexes, ... */
  /* USER CODE END RTOS_MUTEX */

  /* USER CODE BEGIN RTOS_SEMAPHORES */
  /* add semaphores, ... */
  /* USER CODE END RTOS_SEMAPHORES */

  /* USER CODE BEGIN RTOS_TIMERS */
  /* start timers, add new ones, ... */
  /* USER CODE END RTOS_TIMERS */

  /* USER CODE BEGIN RTOS_QUEUES */
  /* add queues, ... */
  /* USER CODE END RTOS_QUEUES */

  /* Create the thread(s) */
  /* creation of defaultTask */
  defaultTaskHandle = osThreadNew(StartDefaultTask, NULL, &defaultTask_attributes);

  /* USER CODE BEGIN RTOS_THREADS */
  /* add threads, ... */
  /* USER CODE END RTOS_THREADS */

  /* USER CODE BEGIN RTOS_EVENTS */
  /* add events, ... */
  /* USER CODE END RTOS_EVENTS */

  /* Start scheduler */
  osKernelStart();

  /* We should never get here as control is now taken by the scheduler */
  /* Infinite loop */
  /* USER CODE BEGIN WHILE */
  while (1)
  {
    /* USER CODE END WHILE */

    /* USER CODE BEGIN 3 */
  }
  /* USER CODE END 3 */
}

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
/* USER CODE BEGIN Header_StartDefaultTask */
/**
  * @brief  Function implementing the defaultTask thread.
  * @param  argument: Not used
  * @retval None
  */
/* USER CODE END Header_StartDefaultTask */
void StartDefaultTask(void *argument)
{
  /* init code for LWIP */
  MX_LWIP_Init();
  /* USER CODE BEGIN 5 */
  /* Infinite loop */
  for(;;)
  {
    osDelay(100);
  }
  /* USER CODE END 5 */
}

/* MPU Configuration */

void MPU_Config(void)
{
  MPU_Region_InitTypeDef MPU_InitStruct = {0};

  /* Disables the MPU */
  HAL_MPU_Disable();

  /** Initializes and configures the Region and the memory to be protected
  */
  MPU_InitStruct.Enable = MPU_REGION_ENABLE;
  MPU_InitStruct.Number = MPU_REGION_NUMBER0;
  MPU_InitStruct.BaseAddress = 0;
  MPU_InitStruct.Size = MPU_REGION_SIZE_4GB;
  MPU_InitStruct.SubRegionDisable = 0x87;
  MPU_InitStruct.TypeExtField = MPU_TEX_LEVEL0;
  MPU_InitStruct.AccessPermission = MPU_REGION_NO_ACCESS;
  MPU_InitStruct.DisableExec = MPU_INSTRUCTION_ACCESS_DISABLE;
  MPU_InitStruct.IsShareable = MPU_ACCESS_SHAREABLE;
  MPU_InitStruct.IsCacheable = MPU_ACCESS_NOT_CACHEABLE;
  MPU_InitStruct.IsBufferable = MPU_ACCESS_NOT_BUFFERABLE;

  HAL_MPU_ConfigRegion(&MPU_InitStruct);

  /** Initializes and configures the Region and the memory to be protected
  */
  MPU_InitStruct.Number = MPU_REGION_NUMBER1;
  MPU_InitStruct.BaseAddress = 0x30020000;
  MPU_InitStruct.Size = MPU_REGION_SIZE_128KB;
  MPU_InitStruct.SubRegionDisable = 0x0;
  MPU_InitStruct.TypeExtField = MPU_TEX_LEVEL1;
  MPU_InitStruct.AccessPermission = MPU_REGION_FULL_ACCESS;
  MPU_InitStruct.IsShareable = MPU_ACCESS_NOT_SHAREABLE;

  HAL_MPU_ConfigRegion(&MPU_InitStruct);

  /** Initializes and configures the Region and the memory to be protected
  */
  MPU_InitStruct.Number = MPU_REGION_NUMBER2;
  MPU_InitStruct.BaseAddress = 0x30040000;
  MPU_InitStruct.Size = MPU_REGION_SIZE_512B;
  MPU_InitStruct.TypeExtField = MPU_TEX_LEVEL0;
  MPU_InitStruct.IsShareable = MPU_ACCESS_SHAREABLE;
  MPU_InitStruct.IsBufferable = MPU_ACCESS_BUFFERABLE;

  HAL_MPU_ConfigRegion(&MPU_InitStruct);
  /* Enables the MPU */
  HAL_MPU_Enable(MPU_HFNMI_PRIVDEF);

}

/**
  * @brief  Period elapsed callback in non blocking mode
  * @note   This function is called  when TIM6 interrupt took place, inside
  * HAL_TIM_IRQHandler(). It makes a direct call to HAL_IncTick() to increment
  * a global variable "uwTick" used as application time base.
  * @param  htim : TIM handle
  * @retval None
  */
void HAL_TIM_PeriodElapsedCallback(TIM_HandleTypeDef *htim)
{
  if (htim->Instance == TIM6) {
    HAL_IncTick();
  }
}

/**
  * @brief  This function is executed in case of error occurrence.
  * @retval None
  */
void Error_Handler(void)
{
  /* USER CODE BEGIN Error_Handler_Debug */
  /* User can add his own implementation to report the HAL error return state */
  __disable_irq();
  while (1)
  {
  }
  /* USER CODE END Error_Handler_Debug */
}

#ifdef  USE_FULL_ASSERT
/**
  * @brief  Reports the name of the source file and the source line number
  *         where the assert_param error has occurred.
  * @param  file: pointer to the source file name
  * @param  line: assert_param error line source number
  * @retval None
  */
void assert_failed(uint8_t *file, uint32_t line)
{
  /* USER CODE BEGIN 6 */
  /* User can add his own implementation to report the file name and line number,
     ex: printf("Wrong parameters value: file %s on line %d\r\n", file, line) */
  /* USER CODE END 6 */
}
#endif /* USE_FULL_ASSERT */

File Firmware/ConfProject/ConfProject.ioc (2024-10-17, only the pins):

Mcu.UserName=STM32H755ZITx
PA0.Signal=S_TIM8_ETR
PA1.Signal=ETH_REF_CLK
PA11.Signal=USB_OTG_FS_DM
PA12.Signal=USB_OTG_FS_DP
PA2.Signal=ETH_MDIO
PA3.Signal=S_TIM5_CH4
PA5.Signal=COMP_DAC12_group
PA7.Signal=ETH_CRS_DV
PA9.Signal=USART1_TX
PB0.Signal=S_TIM3_CH3
PB1.Signal=S_TIM3_CH4
PB13.Signal=ETH_TXD1
PB14.GPIO_Label=LD3 [Red Led]
PB14.Signal=GPIO_Output
PB15.Signal=USART1_RX
PB2.Signal=SPI3_MOSI
PC1.Signal=ETH_MDC
PC10.Signal=SPI3_SCK
PC11.Signal=SPI3_MISO
PC12.GPIO_Label=SPI3_CS
PC12.Signal=GPIO_Output
PC13.Signal=GPXTI13
PC2_C.Signal=ADC3_INP0
PC3_C.Signal=ADC3_INP1
PC4.Signal=ETH_RXD0
PC5.Signal=ETH_RXD1
PC6.Signal=USART6_TX
PC7.Signal=USART6_RX
PC8.GPIO_Label=ADC_STROBE
PC8.Signal=GPIO_Output
PC9.Signal=S_TIM8_CH4
PD12.Signal=S_TIM4_CH1
PD2.Signal=S_TIM3_ETR
PD8.Signal=USART3_TX
PD9.Signal=USART3_RX
PE0.Signal=S_TIM4_ETR
PE1.GPIO_Label=LD2 [Yellow Led]
PE1.Signal=GPIO_Output
PE11.Signal=S_TIM1_CH2
PE13.Signal=S_TIM1_CH3
PE14.Signal=S_TIM1_CH4
PE2.Signal=SPI4_SCK
PE4.Signal=SPI4_NSS
PE6.Signal=SPI4_MOSI
PF6.Signal=SPI5_NSS
PF7.Signal=SPI5_SCK
PF9.Signal=SPI5_MOSI
PG10.GPIO_Label=ADC_READY_STROBE
PG10.Signal=GPIO_Input
PG11.Signal=ETH_TX_EN
PG13.Signal=ETH_TXD0

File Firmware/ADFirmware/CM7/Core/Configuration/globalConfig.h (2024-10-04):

/*
 * globalConfig.h
 *
 *  Created on: Nov 5, 2023
 *      Author: Haris
 */

#ifndef CORE_CONFIGURATION_GLOBALCONFIG_H_
#define CORE_CONFIGURATION_GLOBALCONFIG_H_


/*Driver layer connfiguration*/
/* AnalogIN configuration*/
#define CONF_AIN_MAX_BUFFER_SIZE			500
#define CONF_AIN_ADC_BUFFER_OFFSET			4
#define CONF_AIN_ADC_BUFFER_MARKER			0xA5A5
#define CONF_AIN_MAX_BUFFER_NO				2
#define CONF_DRV_AIN_ADC_TIM_INPUT_CLK		200000000 //HZ

/* Timer configuration*/
#define CONF_DRV_TIMER_MAX_NUMBER_OF_TIMERS 	3
#define CONF_DRV_TIMER_MAX_NUMBER_OF_CHANNELS 	3

/* GPIO configuration*/
#define CONF_GPIO_PORT_MAX_NUMBER			10
#define CONF_GPIO_PIN_MAX_NUMBER			16
#define	CONF_GPIO_INTERRUPTS_MAX_NUMBER		15


#define	CONF_UART_INSTANCES_MAX_NUMBER		4



/*Middleware layer configuration*/
/**/
#define CONF_SSTREAM_CONTROL_TASK_NAME			"Stream control"
#define CONF_SSTREAM_CONTROL_TASK_PRIO			4
#define CONF_SSTREAM_CONTROL_TASK_STACK_SIZE	1024
#define CONF_SSTREAM_STREAM_TASK_NAME			"Stream"
#define CONF_SSTREAM_STREAM_TASK_PRIO			4
#define CONF_SSTREAM_STREAM_TASK_STACK_SIZE		1024
#define CONF_SSTREAM_CONNECTIONS_MAX_NO			2
#define	CONF_SSTREAM_AIN_DEFAULT_RESOLUTION		16
#define	CONF_SSTREAM_AIN_DEFAULT_CLOCK_DIV		1
#define	CONF_SSTREAM_AIN_DEFAULT_CH_SAMPLE_TIME	2
#define	CONF_SSTREAM_AIN_DEFAULT_CH_AVG_RATIO	1
#define	CONF_SSTREAM_AIN_DEFAULT_SAMPLE_TIME	1000
#define CONF_SSTREAM_AIN_VOLTAGE_CHANNEL		1
#define	CONF_SSTREAM_AIN_CURRENT_CHANNEL		2
#define CONF_SSTREAM_AIN_DEFAULT_PRESCALER		49999
#define CONF_SSTREAM_AIN_DEFAULT_PERIOD			3

/**/
#define CONF_SYSTEM_TASK_NAME					"System task"
#define CONF_SYSTEM_TASK_PRIO					5
#define CONF_SYSTEM_TASK_STACK_SIZE				1024
#define CONF_SYSTEM_DEFAULT_DEVICE_NAME			"ACQ Device"
#define CONF_SYSTEM_DEFAULT_DEVICE_NAME_MAX		50

#define	CONF_SYSTEM_ERROR_STATUS_DIODE_PORT		1	//Port B
#define	CONF_SYSTEM_ERROR_STATUS_DIODE_PIN		14

#define	CONF_SYSTEM_LINK_STATUS_DIODE_PORT		4	//Port E
#define	CONF_SYSTEM_LINK_STATUS_DIODE_PIN		1

/**/
#define CONF_NETWORK_TASK_NAME					"Network Task"
#define CONF_NETWORK_TASK_PRIO					3
#define CONF_NETWORK_TASK_STACK_SIZE			1024

#define CONFIG_LOGGING_TASK_NAME				"LOG Task"
#define	CONFIG_LOGGING_STACK_SIZE				1024
#define	CONFIG_LOGGING_PRIO						3

#define CONFIG_CONTROL_TASK_NAME				"Control Task"
#define CONFIG_CONTROL_PRIO						4
#define CONFIG_CONTROL_STACK_SIZE				2048
#define CONFIG_CONTROL_BUFFER_SIZE				1024
#define CONFIG_CONTROL_SERVER_PORT				5000
#define CONF_CONTROL_RESPONSE_OK_STATUS_MSG		"OK"
#define CONF_CONTROL_RESPONSE_ERROR_STATUS_MSG	"ERROR"
#define CONFIG_CONTROL_STATUS_LINK_MAX_NO		3
#define CONFIG_CONTROL_STATUS_LINK_TASK_NAME	"Status Link Task"
#define CONFIG_CONTROL_STATUS_LINK_PRIO			7
#define CONFIG_CONTROL_STATUS_LINK_STACK_SIZE	1024
#define CONFIG_CONTROL_STATUS_MESSAGES_MAX_NO	20

#define CONF_NETWORK_DEVICE_IP_ADDRESS			"192.168.2.110"
#define CONF_NETWORK_DEVICE_IP_MASK				"255.255.255.0"
#define CONF_NETWORK_DEVICE_IP_GW				"192.168.2.1"

#define CONF_ENERGY_DEBUGGER_TASK_NAME				"Energy Debugger Task"
#define CONF_ENERGY_DEBUGGER_TASK_PRIO				5
#define CONF_ENERGY_DEBUGGER_STACK_SIZE				1024
#define CONF_ENERGY_DEBUGGER_BUTTON_PIN				13
#define CONF_ENERGY_DEBUGGER_BUTTON_PIN				13
#define CONF_ENERGY_DEBUGGER_BUTTON_ISR_PRIO		5 //configLIBRARY_MAX_SYSCALL_INTERRUPT_PRIORITY
#define CONF_ENERGY_DEBUGGER_ID_QUEUE_LENGTH		100
#define CONF_ENERGY_DEBUGGER_MESSAGE_BUFFER_LENTH 		100
#define CONF_ENERGY_DEBUGGER_TCP_MESSAGE_BUFFER_LENTH 	200
#define CONF_ENERGY_DEBUGGER_EBP_NAMES_QUEUE_LENGTH	10
#define CONF_ENERGY_DEBUGGER_EBP_QUEUE_LENGTH		10
#define CONF_ENERGY_DEBUGGER_MAX_CONNECTIONS        3

#define CONF_DPCONTROL_TASK_NAME				"DPControl"
#define	CONF_DPCONTROL_TASK_STACK_SIZE			1024
#define	CONF_DPCONTROL_TASK_PRIO		    	3
#define	CONF_DPCONTROL_LOAD_DISABLE_PORT		0	//Port A
#define	CONF_DPCONTROL_LOAD_DISABLE_PIN			6
#define	CONF_DPCONTROL_BAT_DISABLE_PORT			1	//Port B
#define	CONF_DPCONTROL_BAT_DISABLE_PIN			5

#endif /* CORE_CONFIGURATION_GLOBALCONFIG_H_ */

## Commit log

2023-11-04 framework with first sucessfull ping
2023-11-04 Start to remove autogenerated stm32cube code
2023-11-05 Framework structure refactorization
2023-11-06 initial schematic for overvoltage protection
2023-11-06 Interrupt callback added
2023-11-09 Initial not tested version of UART driver
2023-11-17 add directory for schematics, and full circuit drawing
2023-11-19 Advance options button added
2023-11-25 Advance option push button position fixed
2023-11-26 Add Device window functionalities added
2023-11-26 Connected devices overview
2023-11-26 Remove device option added
2023-12-03 add current sense circuit simulation for 5A load
2023-12-03 update schematic with input stage filter
2023-12-28 Add signals and slots for device, path and acquisition options
2024-01-23 Console image and button added, updated consolewnd sig and slot naming
2024-02-15 ADC3 configured inside config project to sync with Timer1
2024-02-15 Clock div and Sample time change functionalities implemented
2024-02-15 ADC Framework (Proof of Convept)
2024-02-16 Toggling led added
2024-02-18 Initial ADC working version
2024-02-19 ADC Driver updated
2024-02-19 Initial stream framework
2024-02-19 ADC configuration within sstream service added
2024-02-25 Voltage and current offset added
2024-02-25 Voltage and current offset control added inside AnalogIN
2024-02-25 Voltage and current control commands added
2024-02-25 Voltage and current offset control added inside GUI
2024-02-25 ADC Averaging ratio integrated inside Driver layer
2024-02-26 Unused signals and slots removed
2024-02-27 Refresh button function add, minor fixes and refactoring
    [device.cpp, device.h, devicecontainer.cpp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]
2024-03-03 Acquisiton device commands list documentation
2024-04-02 add source files for Altium, BOM and pdf
    [Current_SenseSchematic.SchDoc, Current_sense_v1I1.xlsx]
2024-05-05 Max number of samples buffers configured
2024-05-24 add kicad source files, delete altium source files
    [039301020.stp, 1-826664-4--3DModel-STEP-1.STEP, 150352M173300--3DModel-STEP-269445.STEP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]
2024-05-30 File processing error fixed
    [device.h, main.cpp]
2024-06-30 create SPI directory, and add spi source and header files
2024-06-30 enable SPI
2024-06-30 add spi driver
2024-08-03 GUI modified to print EBP info
2024-10-03 Read ADC, RGB control and DAC control addded
2024-10-07 Config project upgraded to support SPI
2024-10-10 Initial working version of ADC
2024-10-10 Driver modified to satisfy naming convention - SPI left
2024-10-10 SPI Driver refactorized
2024-10-17 Initial version of new ADC added

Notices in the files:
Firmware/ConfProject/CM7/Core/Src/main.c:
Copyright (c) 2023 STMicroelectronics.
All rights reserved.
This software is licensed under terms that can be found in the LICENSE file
